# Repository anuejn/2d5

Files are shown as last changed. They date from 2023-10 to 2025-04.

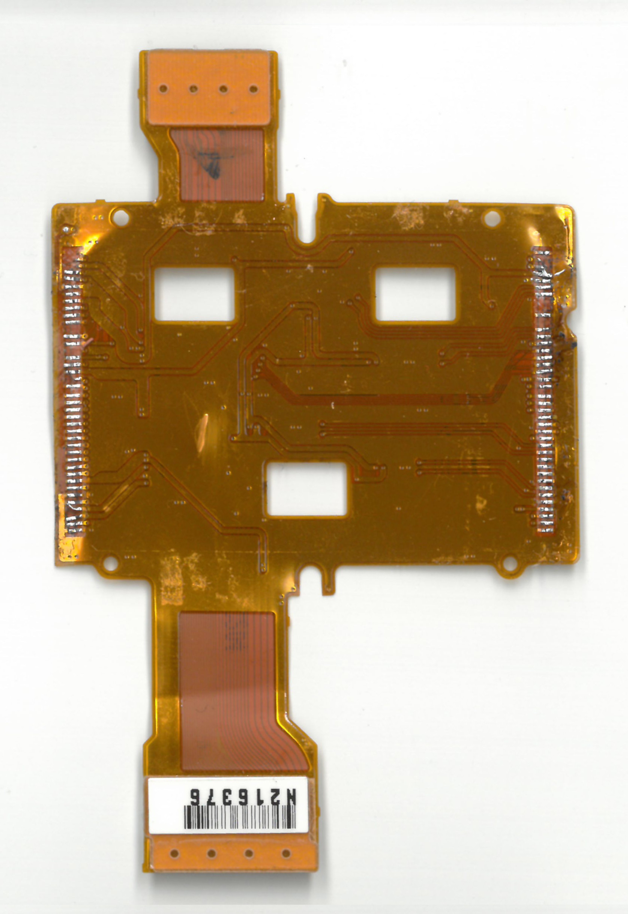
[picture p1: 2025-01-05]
carrier_tracing/front.jpg

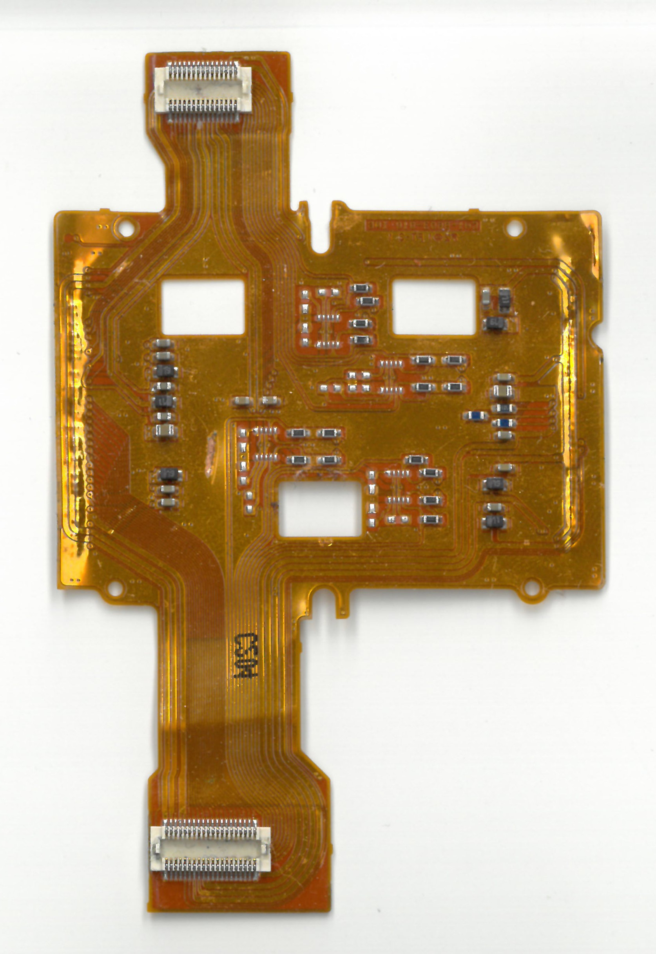
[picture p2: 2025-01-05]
carrier_tracing/back.jpg

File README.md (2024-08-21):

# Reverse engineering 5D mark II (5D2) image sensor

This repository contains notes tools for reverse engineering the image sensor of the Canon EOS 5D mark II
DSLR. The reverse engineering is work in progress and not in a state where the sensor is useable.
The image sensor is relatively cheap available (~40€) and has a "full frame" sized active area
(36mm × 24mm) with 5,616px × 3,744px (21.0 MP). The 5D mark II important in popularizing DSLR cameras
for video making and the Magic Lantern firmware was originally written for this camera.

The best place to start exploring the repository is reading the files on different topics in the
[`docs/`](docs/) directory. Other folders are less easy to follow but contain raw data obtained in 
the reverse engineering process.

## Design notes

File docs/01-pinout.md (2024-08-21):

# Pinout of the Sensor

For driving the sensor outside the camera, it is important to figure out its pinout. In the 5d2 the
sensor is mounted on a flex pcb. I will first focus on figuring out the connections of this flex-pcb.
After this, figuring out the pinout of the actual CMOS should be trivial if needed.

## Connectors

The sensor assembly has 3 connectors:

* larger stacking 20*2 position connector a closeup of the 40 pin connector
* smaller stacking 15*2 position connector a closeup of the 30 pin connector
* other 4 position connector probably going to the vibration cleaning of the sensor

The stacking connectors have the same pitch (0.466mm - 0.475mm measured probably 0.5mm) and are likely of the same series.
Mating height is ~1.5mm.

* Panasonic AXK5F should be fitting (probably original)
* TXGA FBB05001-F40S1003W5M / FBB05001-M40S1013W5M should fit (but is hard to obtain)
* Atom-connector BTB050040-F1S03201 / BTB050040-M1S03201 should fit
* XKB Connectivity X0511FVS-40B-LPV01 / X0511WVS-40A-LPV01 should fit and is on lcsc

A breakout board for intercepting communications between the camera and the sensor can be found
in the [connector_breakout](../connector_breakout) directory. It fits onto the mainboard and adapts the
connectors to 0.1" headers.
a picture of the breakout boards installed on the camera mainboard

## Pinout

Figuring out the pinout is a tricky process that I started with looking at the mainboard visually (see gimp files in `pictures/`),
using a continuity tester and doing different other measurements. After that, I measured voltages
at different pins and looked at the signals with an oscilloscope. Later, I also used different 
logic analyzer setups to trace the signals (see the `traces/` directory).
Throughout the process a warm round of guesswork guided me.
During the probing it was immensely helpful to have the breakout PCBs ordered with
white silkscreen to be able to write results directly to the breakout boards.

The results of my analysis can be found in the [connector pinouts table](../connector_pinouts.ods).
In the whole project, I refer to the pins using their coordinates in this spreadsheet.

The sensor outputs its analog data using differential pairs and requires
a bunch of different power supplies. To get a glimpse on how the interface could look like, see the
[datasheet of the Cypress IBIS4-14000](../interesting_datasheets/Cypress_Semiconductor-IBIS4-14000-M-datasheet.pdf).

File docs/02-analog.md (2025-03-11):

# Analog output of the CMOS

The image sensor outputs at four channels differentially. after each pixel, the differential output
goes to 0mV differential value. This is probably to enable Correlated Double Sampling (CDS).
Each side (positive and negative) is centered at ~1.4V and has 300-400mv Swing. The differential
values range from -600mV to +600mV.

## Possible ADCS

The stock adc/afe ic in the camera seems to sample at 24Msa/s.

| part | channels | sample rate [Msa/s] | bit depth | price | notes |
| :--- | :--- | :--- | :--- | :--- | :--- |
| VSP5610 | 4 | 8.75 | 16 | 6 | no register reference |
| ADDI7004  | 4 | 72 | 14 | 65$ | |
| ADC34J45  | 4 | 160 | 14 | 81$ | only ADC |
| ADC3422 | 4 | 50 | 12 | 25 | only ADC |
| ADC3244 | 2 | 125 | 14 | 26$ @1k | only ADC |
| HMCAD1520 | 4 | 160 | 12 | 121$ | only ADC |
| HMCAD1511 | 4 | 125 | 8 | 13$ | only ADC |
| AD9228 | 4 | 40 | 12 | 30 | only ADC |
| AD9235 | 1 | 65 | 12 | 11 | only ADC |
| ADS4222 | 2 | 65 | 12 | 11 | only ADC |
| AD9253 | 4 | 105 | 14 | 50 | only adc |
| AD9637 | 8 | 80 | 12 | 28 | only adc |
| MS9842SS  | 1 | 15 | 16 | 1 | same as HT82V42, only single ended input |
| LM98725 | 3 | 81 | 16 | 17 | |
| LM98714 | 3 | 45 | 16 | 12 | |

There is a test-board with a HMCAD1511 in the [zynq-test-board/](../zynq-test-board/) folder.

### HMCAD1511

I invested some efford trying to get 12 bit output from the HMCAD1511. This however is not trivial
and maybe outright impossible. It is not just the same die as the HMCAD1520 or at least it is 
configured a bit differently.

One possibility would be to use multiple 8 bit ADCs in an "Alexa Style" configuration with different
gains to reach higher dynamic range.

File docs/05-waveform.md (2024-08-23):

# Waveform of the image sensor

The image sensor consists of 3 main time periods. We decide that we base all our math off the middle
one, A line period. A line period starts at a rising edge of J21.

Signals to investigate:
* How does J10 actually look??? -> like in the newer la trace
* Is C3 having a signal? (line) -> yes
* Is C6 having a signal? (line) -> yes
* Is C5 having a signal? (frame) -> yes (once per frame for ~10 lines)

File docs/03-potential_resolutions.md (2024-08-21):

## Potential Resolutions:

The 5d2 sensor outputs analog values (no on chip ADC) with 4 channel readout.
The camera drives the sensor with a 24Mhz pixel clock. It is unclear how much faster the sensor can
be driven.

Required sample rates (purely theoretical; there will be some overhead):

| Format | resolution | framerate | pixel rate / 4 [Mpix/s] |
| :--- | :--- | :--- | :--- |
| FHD | 1920x1080  | 24 | 12.4416 |
| FHD actual cam  | 1872x1248  | 24 | 14.01753 |
| FHD | 1920x1080  | 30 | 15.552 |
| FHD actual cam  | 1872x1248  | 30 | 17.52192 | 
| HALF 16:9 | 2808x1580  | 24 | 26.61984 |
| FHD | 1920x1080  | 60 | 31.104 |
| HALF | 2808x1872  | 24 | 31.53945 |
| HALF 16:9 | 2808x1580  | 30 | 33.2748 |
| HALF | 2808x1872  | 30 | 39.42432 |
| camera 1080p | 5568x1044  | 30 | 43.59744 |
| FULL 3-lineskip | 5568x1248  | 30 | 52.11648 |
| 4k 16:9 (CROP)  | 4096x2304  | 24 | 56.62310 |
| HALF 16:9 | 2808x1580  | 60 | 66.5496 |
| 4k 16:9 (CROP)  | 4096x2304  | 30 | 70.77888 |
| HALF | 2808x1872  | 60 | 78.84864 |
| FULL 21:9 | 5616x2407  | 24 | 81.10627 |
| FULL 21:9 | 5616x2407  | 30 | 101.3828 |
| FULL 16:9 | 5616x3159  | 24 | 106.4456 |
| FULL | 5616x3744  | 24 | 126.1578 |
| FULL 16:9 | 5616x3159  | 30 | 133.0570 |
| 4k 16:9 (CROP)  | 4096x2304  | 60 | 141.5577 |
| FULL | 5616x3744  | 30 | 157.6972 |

Notes:

* The camera is [reported to use a column 3x binning and row 3x skipping](https://www.magiclantern.fm/forum/index.php?topic=16516.0)
  in its video mode. The FHD mode seems to use on-chip row and column skipping and a slightly-less than FHD readout with digital upscaling
  for the FHD video output.
* It is unclear what other row / column subsampling modes are possible with the sensor interface (concerns HALF, FHD and CROP modes)
* 4k DCI would have a crop factor of 1.371 (vs 1.6 for APSC)
* USB 3.0 can theoretically transport 500Mbyte/s as a theoretical maximum and probably not much more than 400Mbyte/s in practice.
* Actual ADC speed would need to be twice as high for correlated double sampling (CDS) or would require additional analog circutry

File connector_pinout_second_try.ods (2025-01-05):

line |  |  | 2v8
 |  | GND | 5v
frame | 5v | GND | pxclk
line | pxclk | GND | GND
2v9 | GND | startup | GND
line | Analog Data | startup | line
-1v3 | GND | 2v | frame
1v3 | Analog Data | 1v3 | line
5v | GND | 5v | line
-1v3 | Analog Data | 5v | line
 | GND | GND | x
SPI DATA | Analog Data | Analog Data
SPI CLK | GND | GND | line
SPI CS | GND | Analog Data | line
line | 1v3 | GND | line
 |  | Analog Data | line
 |  | GND | startup
 |  | Analog Data | 3v
 |  | GND | line
 |  | 1v5
 | 5v
 | 3v
 | 2v9
 | 2v8
 | 2v
 | 1v5
 | 1v3
 | -1v3

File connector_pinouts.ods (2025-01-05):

 |  | Pinout 30pin connector |  |  |  |  |  | Pinout 40pin connector
 |  |  |  |  |  |  |  |  |  |  | pulses per Y-reset
41,958Khz | line? | Digital North | Digital North | 0 |  |  | Startup / Shutdown / mode change | Digital North | PWR north (without c) | 2,8v
 | floating? | Digital North | Digital North | 0 |  |  |  | GND | 5V | 5,081v
 | floating? | Digital North | 5V | 5,08v |  |  |  | GND | Digital North | Pxclk | 2753 | !!!
 | line | Digital North | Digital North | Pxclk |  |  |  | GND | GND
 | 2.4v | Digital North | GND |  |  | Startup hang? |  | Digital South | GND
41,958Khz | line | Digital North | Analog Data |  |  | Startup / Shutdown |  | Digital South | Digital North | line? | 2681
 | -1,316v | PWR | GND |  |  | Enable? | 2,029v | PWR South | Digital North | Y-reset? | 1
0.86uF to GND | 1,3762v / 0.9v | PWR thin | Analog Data |  |  | Startup charge? | 1,3048v | PWR South | Digital North | line many pulses | 3576
 | 4,969v | PWR | GND |  |  |  | 5,082v | 5V | Digital North | active high line | 894 | Maybe 0
 | -1,3163v | PWR pair | Analog Data |  |  |  | 5,082v | 5V | Digital North | line enable? | 894 | Maybe 0
 | ???GND??? | ??? | GND |  |  |  |  | GND | Digital North | startup? | 0
30Hz / 2Mhz / 4Mhz | Data? | UNK via | Analog Data |  |  |  |  | Analog Data | Digital North | ????????
30Hz / 2Mhz / 4Mhz | ClK? | 2 | GND |  |  |  |  | GND | Digital North | line multiple pulses? |  | ??
30Hz | 6 Pulses per frame? | UNK via | GND |  |  |  |  | Analog Data | Digital North | line with skip? | 1788
41,958Khz | line | UNK via | PWR? | 1,305v | Startup charge? |  |  | GND | Digital North | line? | 893
 |  |  |  |  |  |  |  | Analog Data | Digital North | line? | 893
 |  |  |  |  |  |  |  | GND | Digital North | startup? | -
 |  |  |  |  |  |  |  | Analog Data | Digital North | enable? | -
 |  |  |  |  |  |  |  | GND | Digital North | line? | 894
 |  |  |  |  |  | Enable? | 1,501v | PWR south | Digital North | 0 | -
 |  | Voltages:
 |  |  | 5V
 |  |  | 2.8
 |  |  | 2.4
 |  |  | 2.
 |  |  | 1.5
 |  |  | 1.3
 |  |  | -1.3

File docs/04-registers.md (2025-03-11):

# Registers of the Sensor
* The Sensor seems to have 6 registers (0 - 5) with 12 bit each
* they are written with an SPI bus that is active when CS (C16) is high
* There are other devices on the SPI bus (probably the ADTGs), so not all trafic is for the sensor
* The clock is C15, data is on C14. Data is valid on the rising edge of the clock.
* The SPI bus has transactions with 16 bits each. The first 4 bits are the adress of the register
  while the last 12 bits are the value. 

There is documentation on the register map [in the magic lantern wiki](https://magiclantern.fandom.com/wiki/ADTG)
and in the magic lantern [adtg_gui code](https://github.com/reticulatedpines/magiclantern_simplified/blob/df4c7bd32ec0cd65a4b6aacdd7ec5cce1c560135/modules/dev_tools/adtg_gui/adtg_gui.c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).

## Register states in different situations: 
This section contains observations of the register set in different situations. 
They are the state during capture and are captured with either a glasgow or a logic analyzer.

### Different modes
```
photo:           0203 1C00 2008 3007 4242 5C05
normal liveview: 020f 1c00 240e 3005 4242 5c01
fhd:             020f 1c00 240e 3005 4242 5c01
```

### Experimentation with the LiveView Zoom
```
5x zoom center:              020f 1e6a 210e 3005 4242 5c01
5x zoom upper right corner:  020f 1d20 220e 3005 4242 5c01
5x zoom upper left corner:   020f 1d20 200e 3005 4242 5c01
5x zoom lower right corner:  020f 1c18 220e 3005 4242 5c01
5x zoom lower left corner:   020f 1c18 200e 3005 4242 5c01
```

10x modes have the exact same registers and are implemented in software.

### Experimentation with ISO (all of this is in LiveView)
```
ISO 100:  0203 1c00 240e 3005 4242 5c01
ISO 160:  0207 1c00 240e 3005 4242 5c01
ISO 320:  020b 1c00 240e 3005 4242 5c01
ISO 640:  020f 1c00 240e 3005 4242 5c01
ISO 1250: 0213 1c00 240e 3005 4244 5c01
ISO 2500: 0213 1c00 240e 3005 4244 5001
```

## Conclusions:

conclusions prefixed with "ML:" are not my findings but rather copied from the Magic Lantern

### CMOS[0]
```
---- ---- --xx ML: default 11, setting to 00 results in dark image with very low stdev
---- ---x xx-- ISO coarse (0 - 4)
---- xxx- ---- ML: ISO2
---x ---- ---- ML: ISO2 enable (according to ML)
--x- ---- ---- ML: enables vertical OB clamping maybe (setting it to 0 results in severe horizontal banding that looks like random walk)
-x-- ---- ---- ML: compresses the image horizontally (left side squashed, right side black)
0010 0000 0011 "normal"
```

### CMOS[1]
```
---- ---x xxx-  y start offset 0 - 12
1100 0000 0000 "normal"
1110 0110 1010 "zoom center"
1101 0010 0000 "zoom upper"
1100 0001 1000 "zoom lower"

top to bottom sweep zoomed in:
1101 0110 0010
1101 1010 0100
1101 1110 0110
1110 0010 1000
1110 0110 1010
1110 1010 1100
1110 1110 1110
1111 0011 0000
1111 0111 0010
1111 1011 0100
1111 1111 0110
1100 0001 1000
```

### CMOS[2]
```
-x-- ---- ---- binning?
--xx ---- ---- coarse x offset? (left = 0, center = 1, right = 2)
---- ---- -xx- only set in liveview-esque modes
0000 0000 1000 "photo"
0100 0000 1110 "liveview"
0001 0000 1110 "zoom center"
0010 0000 1110 "zoom right"
0000 0000 1110 "zoom left"
0010 0000 1100 Temporary cleanup state during zoomed in sweep in LV
```

### CMOS[3]
```
---- ---- --x-  magic photo bit?
0000 0000 0111 "photo"
0000 0000 0101 "liveview
```

### CMOS[4]
```
---- ---- -xx- analog mux (one hot) for high conversion gain? (0b01 = ISO < 1250; 0b10 = ISO >= 1250)
---x ---- ---- ML: looks like some vertical dual ISO
-x-- ---- ---- ML: seems to cleanup 0.2 or 0.25 stops of shadow noise
No effect observed on the other bits.
0010 0100 0010 ISO < 1250
0010 0100 0100 ISO >= 1250
```

### CMOS[5]
```
xx-- ---- ---- ISO related (00 = LOW ISO, 11 = ISO >= 2500)
---- ---- -x-- Photo Mode Bit
1100 0000 0101 Photo
1100 0000 0001 LV
0000 0000 0001 LV ISO >= 2500
0100 0000 0101 Temporary cleanup state during zoomed in sweep in LV
```

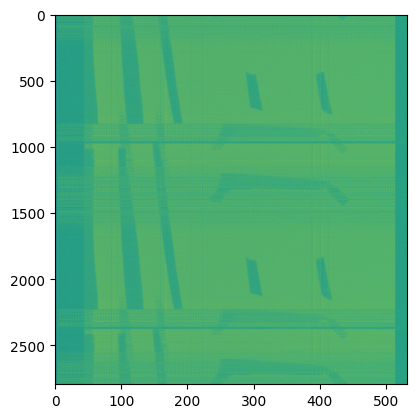
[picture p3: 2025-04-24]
traces/25-04-24/output.png

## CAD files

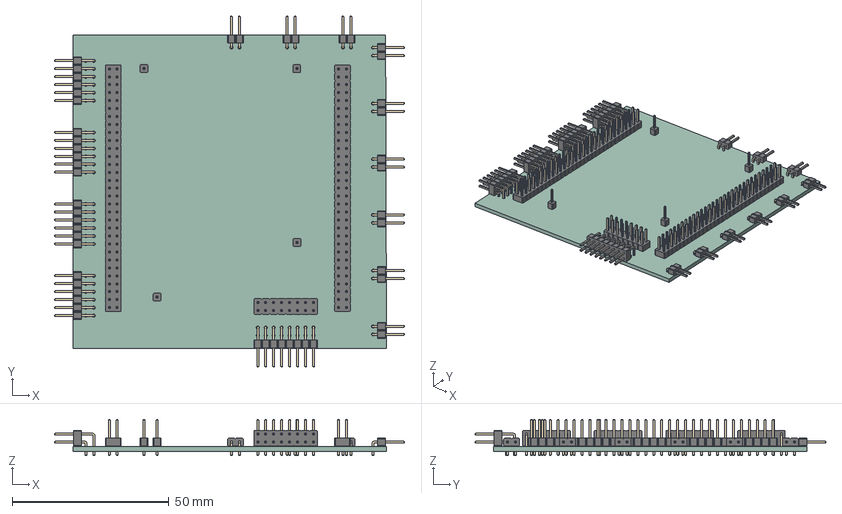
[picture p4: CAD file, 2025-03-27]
boards/hedgehog/5d2_pmod/5d2_pmod.step
111.7 x 112.0 x 11.5 mm
PinHeader_2x31_P254mm_Vertical x 2
PinHeader_1x01_P254mm_Vertical x 4
PinHeader_2x06_P254mm_Horizontal x 4
PinHeader_1x02_P254mm_Horizontal x 9
PinHeader_2x08_P254mm_Vertical
PinHeader_2x08_P254mm_Horizontal
5d2_pmod_PCB

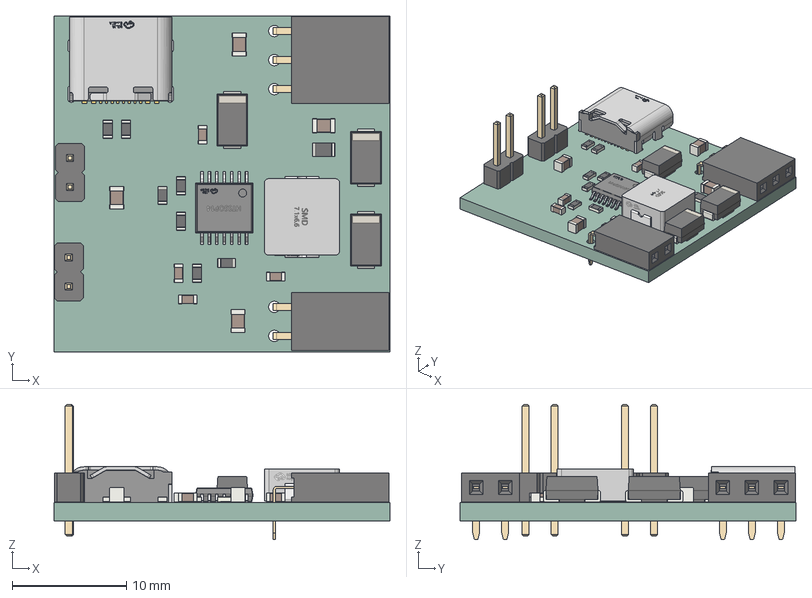
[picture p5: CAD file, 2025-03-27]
boards/hedgehog/power_base/power_base.step
29.4 x 29.4 x 11.8 mm
PinHeader_1x02_P254mm_Vertical x 2
PinSocket_1x03_P254mm_Horizontal
USB-C-SMD_TYPE-C-6PIN-2MD-073
C_0603_1608Metric x 4
C_0805_2012Metric x 4
HTSSOP-14_L5.0-W4.4-H1.2-LS6.4-P0.65
IND-SMD_L7.1-W6.6-H2.8
R_0603_1608Metric x 7
D_SMA x 3
PinSocket_1x02_P254mm_Horizontal
R_0805_2012Metric
power_base_PCB

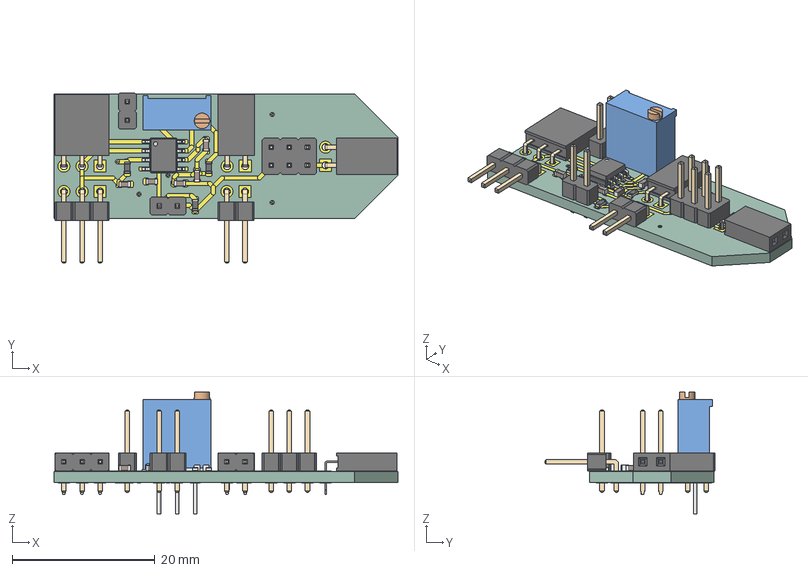
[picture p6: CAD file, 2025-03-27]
boards/hedgehog/power_leg_positive/power_leg_positive.step
48.3 x 23.9 x 17.1 mm
SOIC_8_39x49mm_P127mm
C_0603_1608Metric x 5
R_0603_1608Metric x 3
PinHeader_1x03_P254mm_Horizontal
PinHeader_1x02_P254mm_Vertical x 2
PinSocket_1x02_P254mm_Horizontal x 2
PinSocket_1x03_P254mm_Horizontal
PinHeader_1x02_P254mm_Horizontal
PinHeader_2x03_P254mm_Vertical
Potentiometer_Bourns_3296W_Vertical
power_leg_positive_track_1
power_leg_positive_track_2
power_leg_positive_track_3
power_leg_positive_track_4
power_leg_positive_track_5
power_leg_positive_track_6
power_leg_positive_track_7
power_leg_positive_track_8
power_leg_positive_track_9
power_leg_positive_track_10
power_leg_positive_track_11
power_leg_positive_track_12
power_leg_positive_track_13
power_leg_positive_track_14
power_leg_positive_track_15
power_leg_positive_track_16
power_leg_positive_track_17
power_leg_positive_track_18
power_leg_positive_track_19
power_leg_positive_track_20
power_leg_positive_track_21
power_leg_positive_track_22
power_leg_positive_track_23
power_leg_positive_track_24
power_leg_positive_track_25
power_leg_positive_track_26
power_leg_positive_track_27
power_leg_positive_track_28
power_leg_positive_track_29
power_leg_positive_track_30
power_leg_positive_track_31
power_leg_positive_track_32
power_leg_positive_track_33
power_leg_positive_track_34
power_leg_positive_track_35
power_leg_positive_track_36
power_leg_positive_track_37
power_leg_positive_track_38
power_leg_positive_track_39
power_leg_positive_track_40
power_leg_positive_track_41
power_leg_positive_track_42
power_leg_positive_track_43
power_leg_positive_track_44
power_leg_positive_track_45
power_leg_positive_track_46
power_leg_positive_track_47
power_leg_positive_track_48
power_leg_positive_track_49
power_leg_positive_track_50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

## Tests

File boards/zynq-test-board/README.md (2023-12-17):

# zynq test board

This board is a "cape" for the [z-turn lite](https://www.myirtech.com/list.asp?id=565)zynq SBC and
should serve as a development basis for interfacing the sensor. 
It features an HMCAD1511TR as ADC and appropriate power-supplies. Otherwise it does very little.

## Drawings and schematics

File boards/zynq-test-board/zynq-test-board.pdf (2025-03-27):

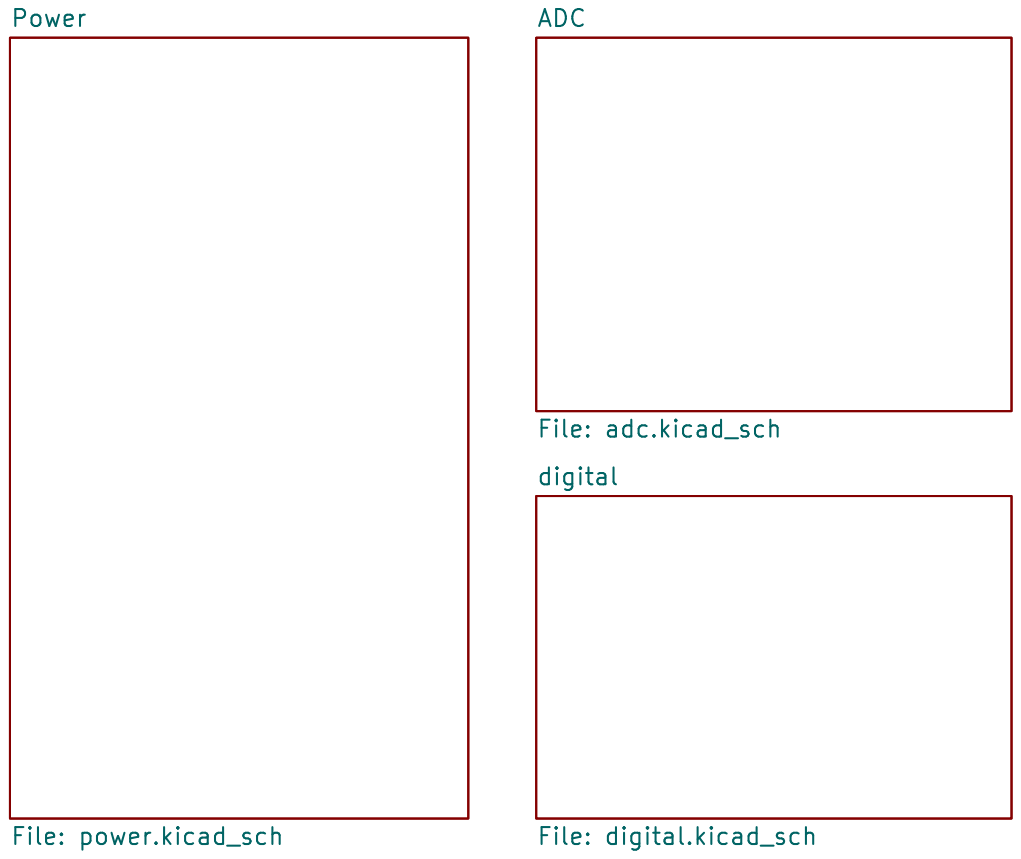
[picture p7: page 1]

digital File: digital.kicad_sch ADC

File: zynq-test-board.kicad_sch Sheet: / Apertus

Id: 1/16 Title: 2D5 experiment board

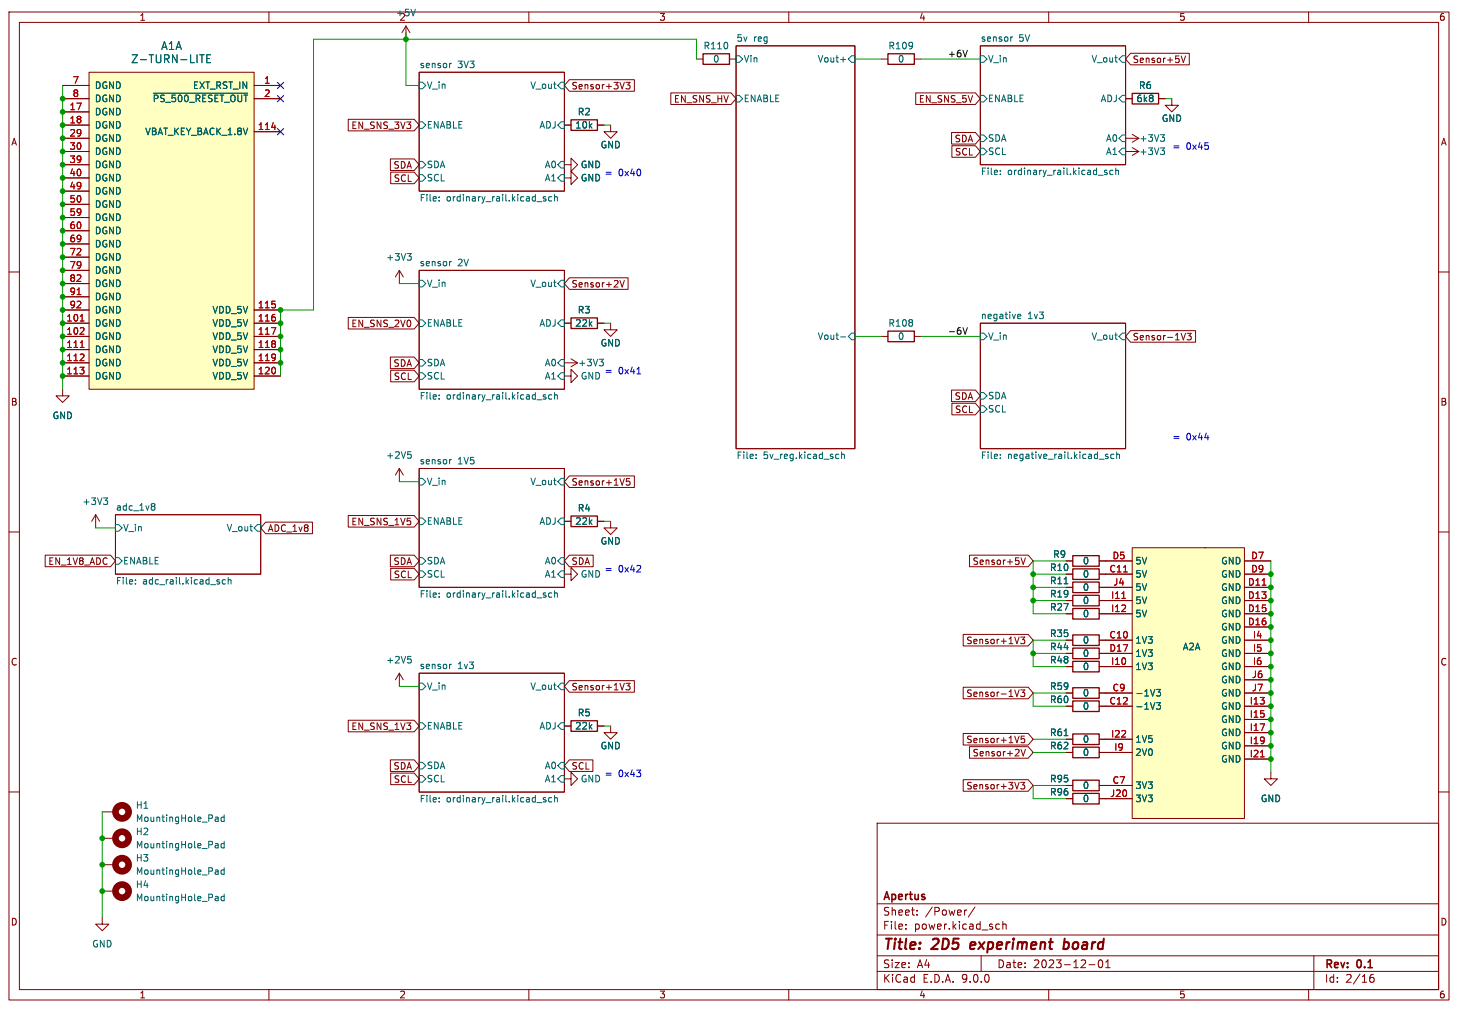
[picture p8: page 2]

File: power.kicad_sch Sheet: /Power/ Apertus

Id: 2/16 Title: 2D5 experiment board

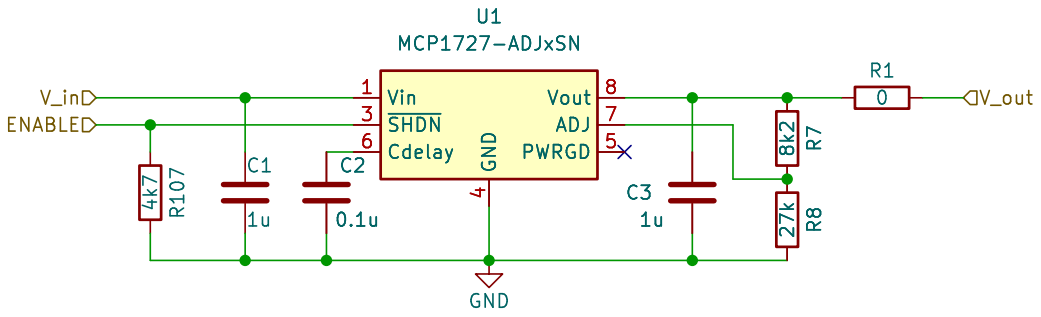
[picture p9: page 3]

File: adc_rail.kicad_sch Sheet: /Power/adc_1v8/
Id: 3/16 Title: 2D5 experiment board

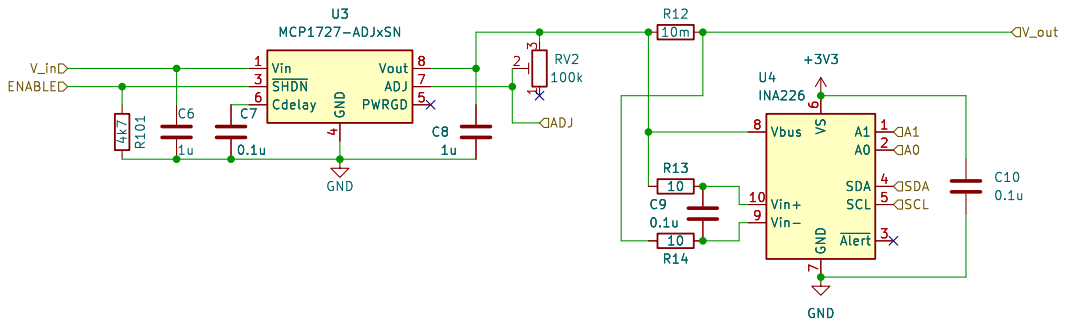
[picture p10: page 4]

7 A1 1 A0 2 SDA 4 SCL 5 ~{Alert}3 GND

Id: 3/16 Title: 2D5 experiment board

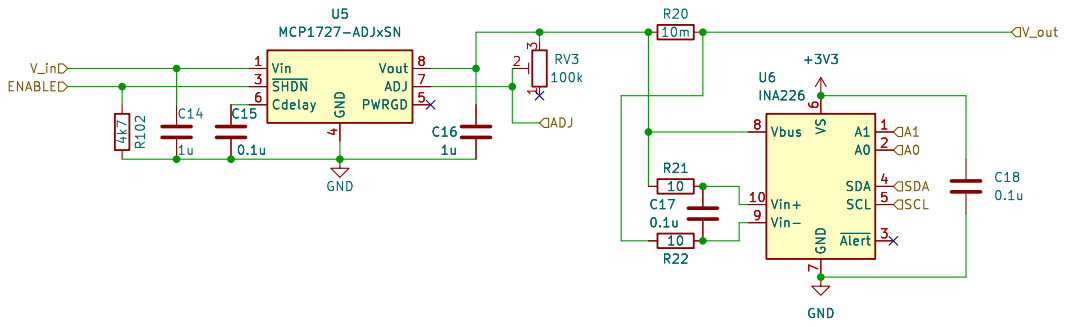
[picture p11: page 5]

7 A1 1 A0 2 SDA 4 SCL 5 ~{Alert}3 GND

Id: 4/16 Title: 2D5 experiment board

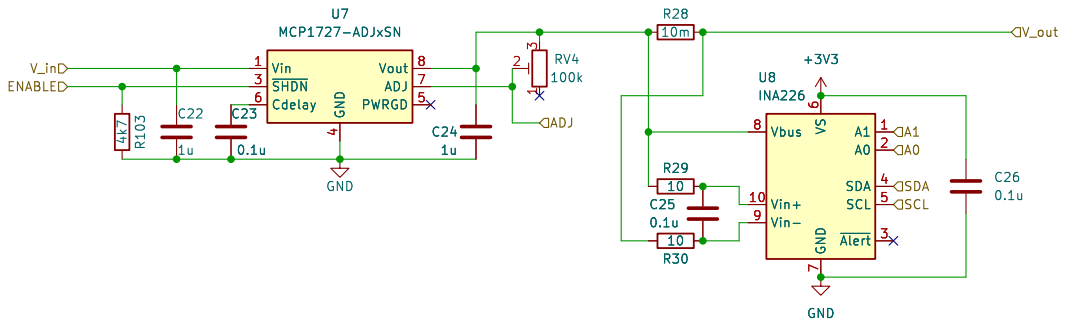
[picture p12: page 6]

7 A1 1 A0 2 SDA 4 SCL 5 ~{Alert}3 GND

Id: 5/16 Title: 2D5 experiment board

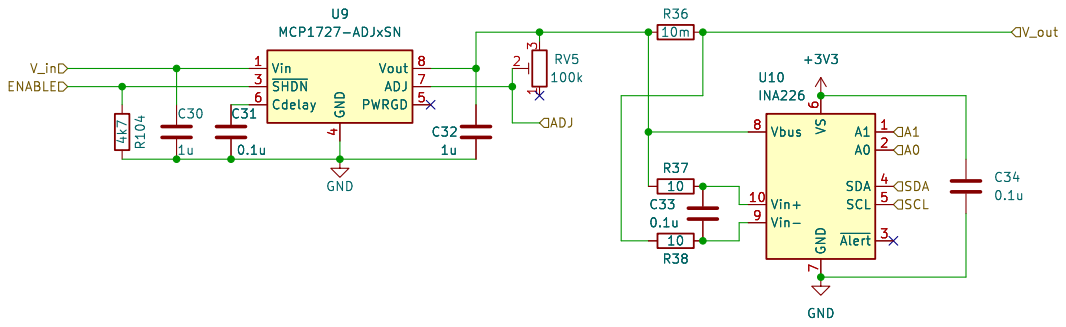
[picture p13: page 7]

7 A1 1 A0 2 SDA 4 SCL 5 ~{Alert}3 GND

Id: 6/16 Title: 2D5 experiment board

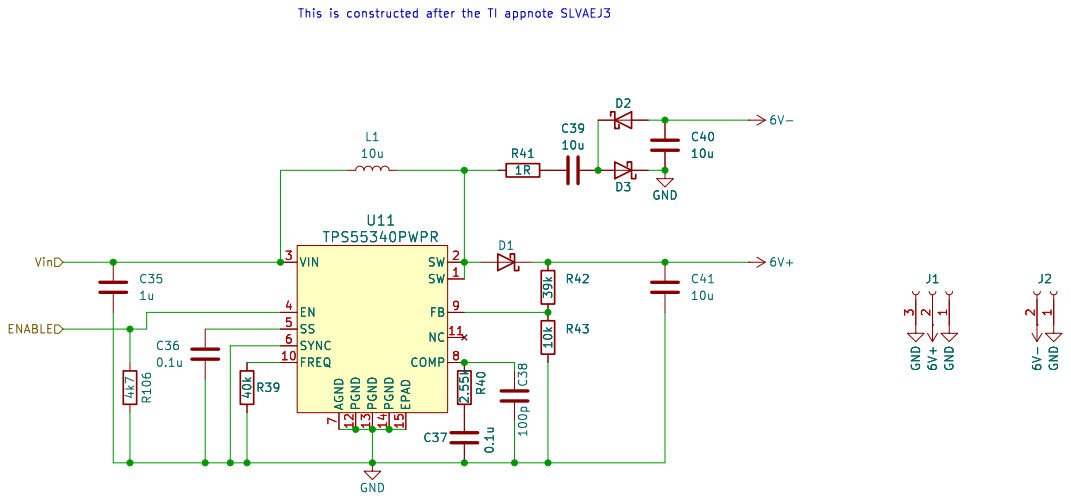
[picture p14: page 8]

7 PGND 12 PGND 13 PGND 14 EPAD 15 SW 2 SW 1 FB 9 NC 11 COMP 8 C37 0.1u R40 2.55k R41

7 PGND 12 PGND 13 PGND 14 EPAD 15 SW 2 SW 1 FB 9 NC 11 COMP 8 U11 TPS55340PWPR GND

Id: 7/16 Title: 2D5 experiment board

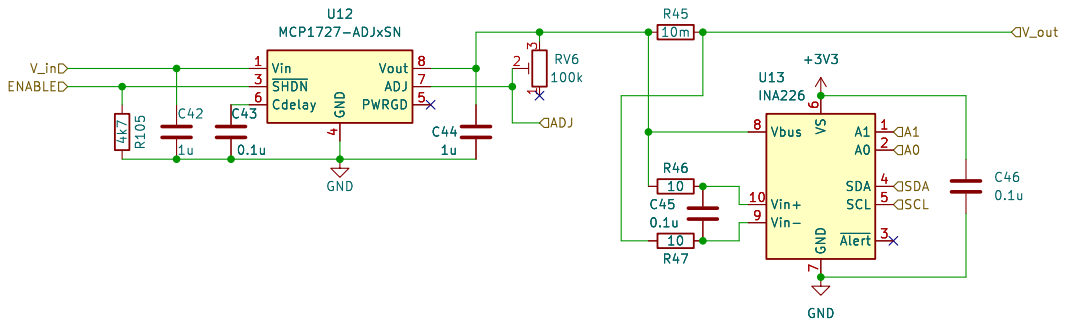
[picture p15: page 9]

7 A1 1 A0 2 SDA 4 SCL 5 ~{Alert}3 GND

Id: 8/16 Title: 2D5 experiment board

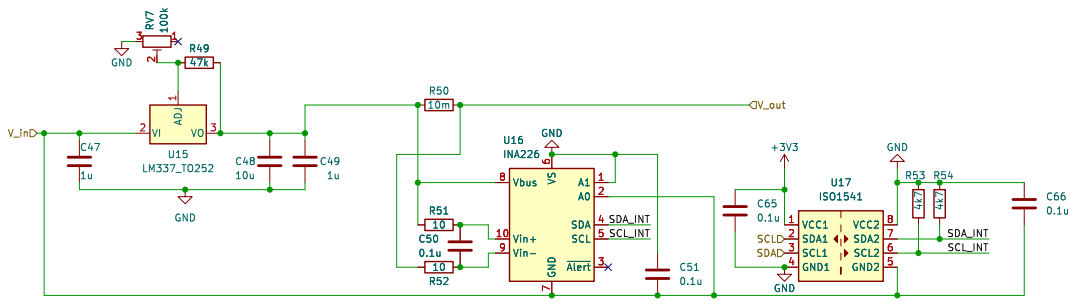
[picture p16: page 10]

7 A1 1 A0 2 SDA 4 SCL 5 ~{Alert}3 GND

Id: 9/16 Title: 2D5 experiment board

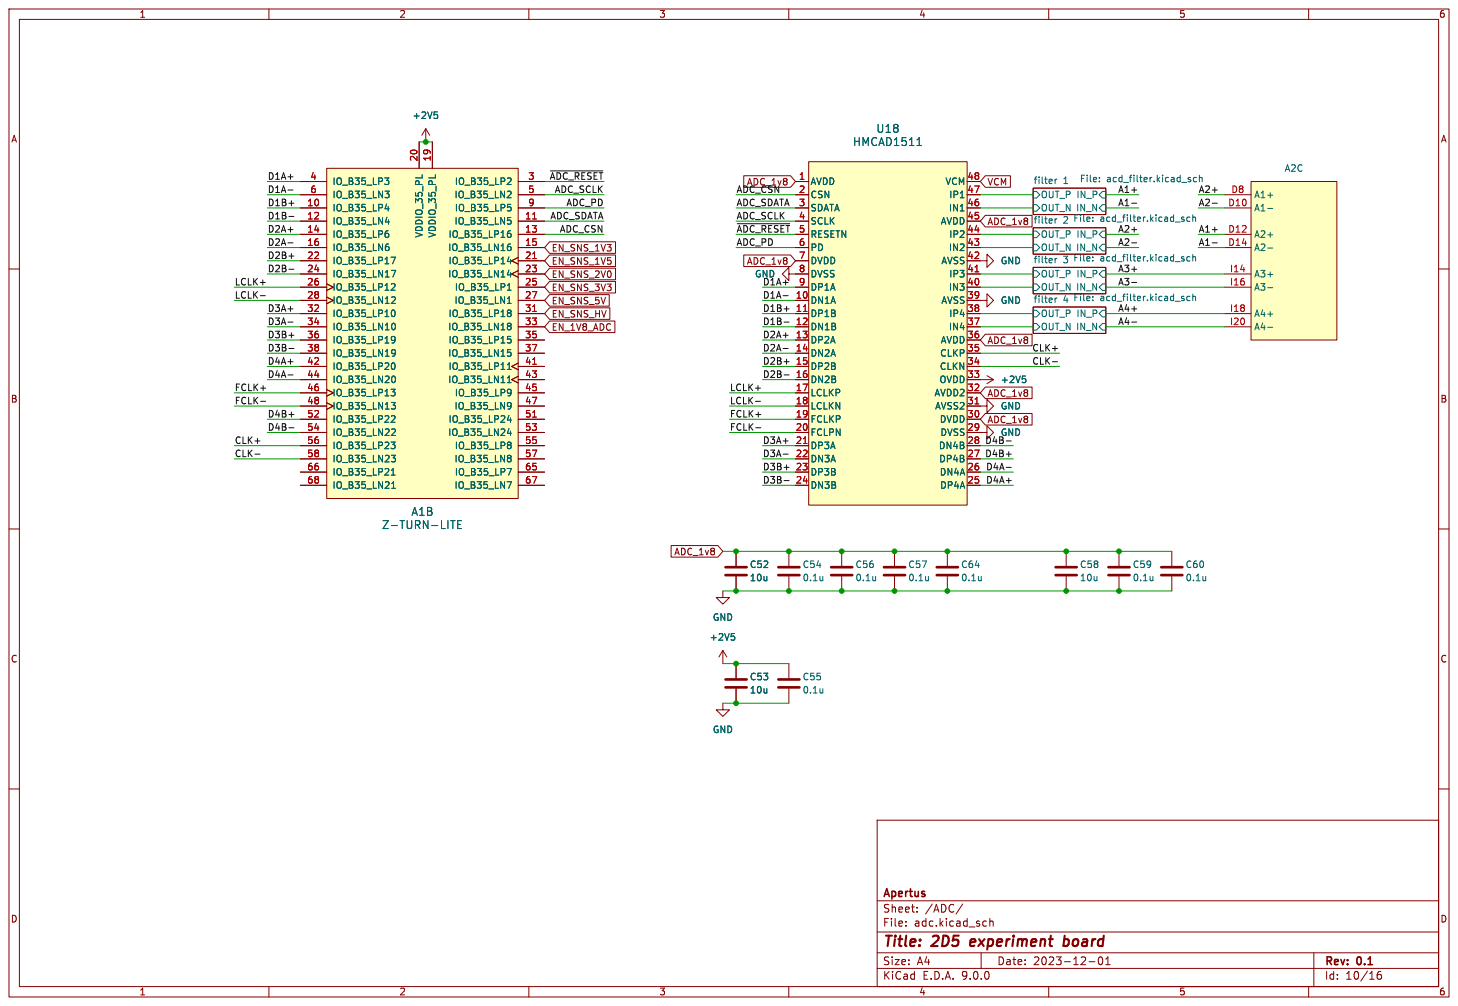
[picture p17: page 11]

File: adc.kicad_sch Sheet: /ADC/ Apertus

Id: 10/16 Title: 2D5 experiment board

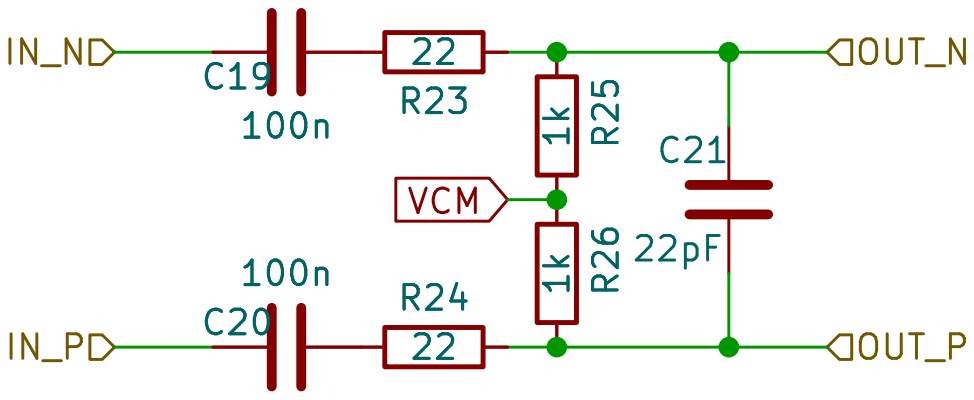
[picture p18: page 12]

Id: 11/16 Title: 2D5 experiment board


Id: 12/16 Title: 2D5 experiment board


Id: 13/16 Title: 2D5 experiment board


Id: 14/16 Title: 2D5 experiment board


Apertus
File: digital.kicad_sch Sheet: /digital/
Id: 15/16 Title: 2D5 experiment board

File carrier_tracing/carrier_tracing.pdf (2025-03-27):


81012141618202224262830 +1V3_TOP GND GND GND GND +5Vb +5Vb GND GND GND GND GND +5V +2V8 +1V3_BOT +1V5 GND

+1V3_TOP
D7 GND GND GND GND

smells more analog domain

and some kind of core voltage?

these might be related to analog IO?
though on the wrong side

Id: 1/5 Title: File: carrier_tracing.kicad_sch Sheet: /

only used in the unpopulated


Id: 2/5 Title: File: mystery_ic.kicad_sch Sheet: /mystery_0/ R22R


Id: 3/5 Title: File: mystery_ic.kicad_sch Sheet: /mystery_1/ R17R


Id: 4/5 Title: File: mystery_ic.kicad_sch Sheet: /mystery_2/ R5R


Id: 5/5 Title: File: mystery_ic.kicad_sch Sheet: /mystery_3/ R11R

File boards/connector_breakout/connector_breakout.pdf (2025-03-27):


Id: 1/1 Title: File: connector_breakout.kicad_sch Sheet: /

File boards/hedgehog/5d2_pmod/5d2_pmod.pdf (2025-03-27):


Id: 1/1 Title: File: 5d2_pmod.kicad_sch Sheet: / 13579

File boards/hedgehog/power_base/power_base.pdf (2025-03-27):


10u GND GND GND GND

7 PGND 12 PGND 13 PGND 14 EPAD 15 SW 2 SW 1 FB 9 NC 11 COMP 8 C9

7 PGND 12 PGND 13 PGND 14 EPAD 15 SW 2 SW 1 FB 9 NC 11 COMP 8 U1 TPS55340PWPR

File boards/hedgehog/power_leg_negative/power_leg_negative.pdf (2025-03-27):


Id: 1/1 Title: File: power_leg_negative.kicad_sch Sheet: /

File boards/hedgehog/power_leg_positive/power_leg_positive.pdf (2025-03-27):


Id: 1/1 Title: File: power_leg_positive.kicad_sch Sheet: /

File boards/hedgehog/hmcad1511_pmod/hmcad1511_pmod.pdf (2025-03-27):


Id: 1/1 Title: HMCAD1511 PMOD Module

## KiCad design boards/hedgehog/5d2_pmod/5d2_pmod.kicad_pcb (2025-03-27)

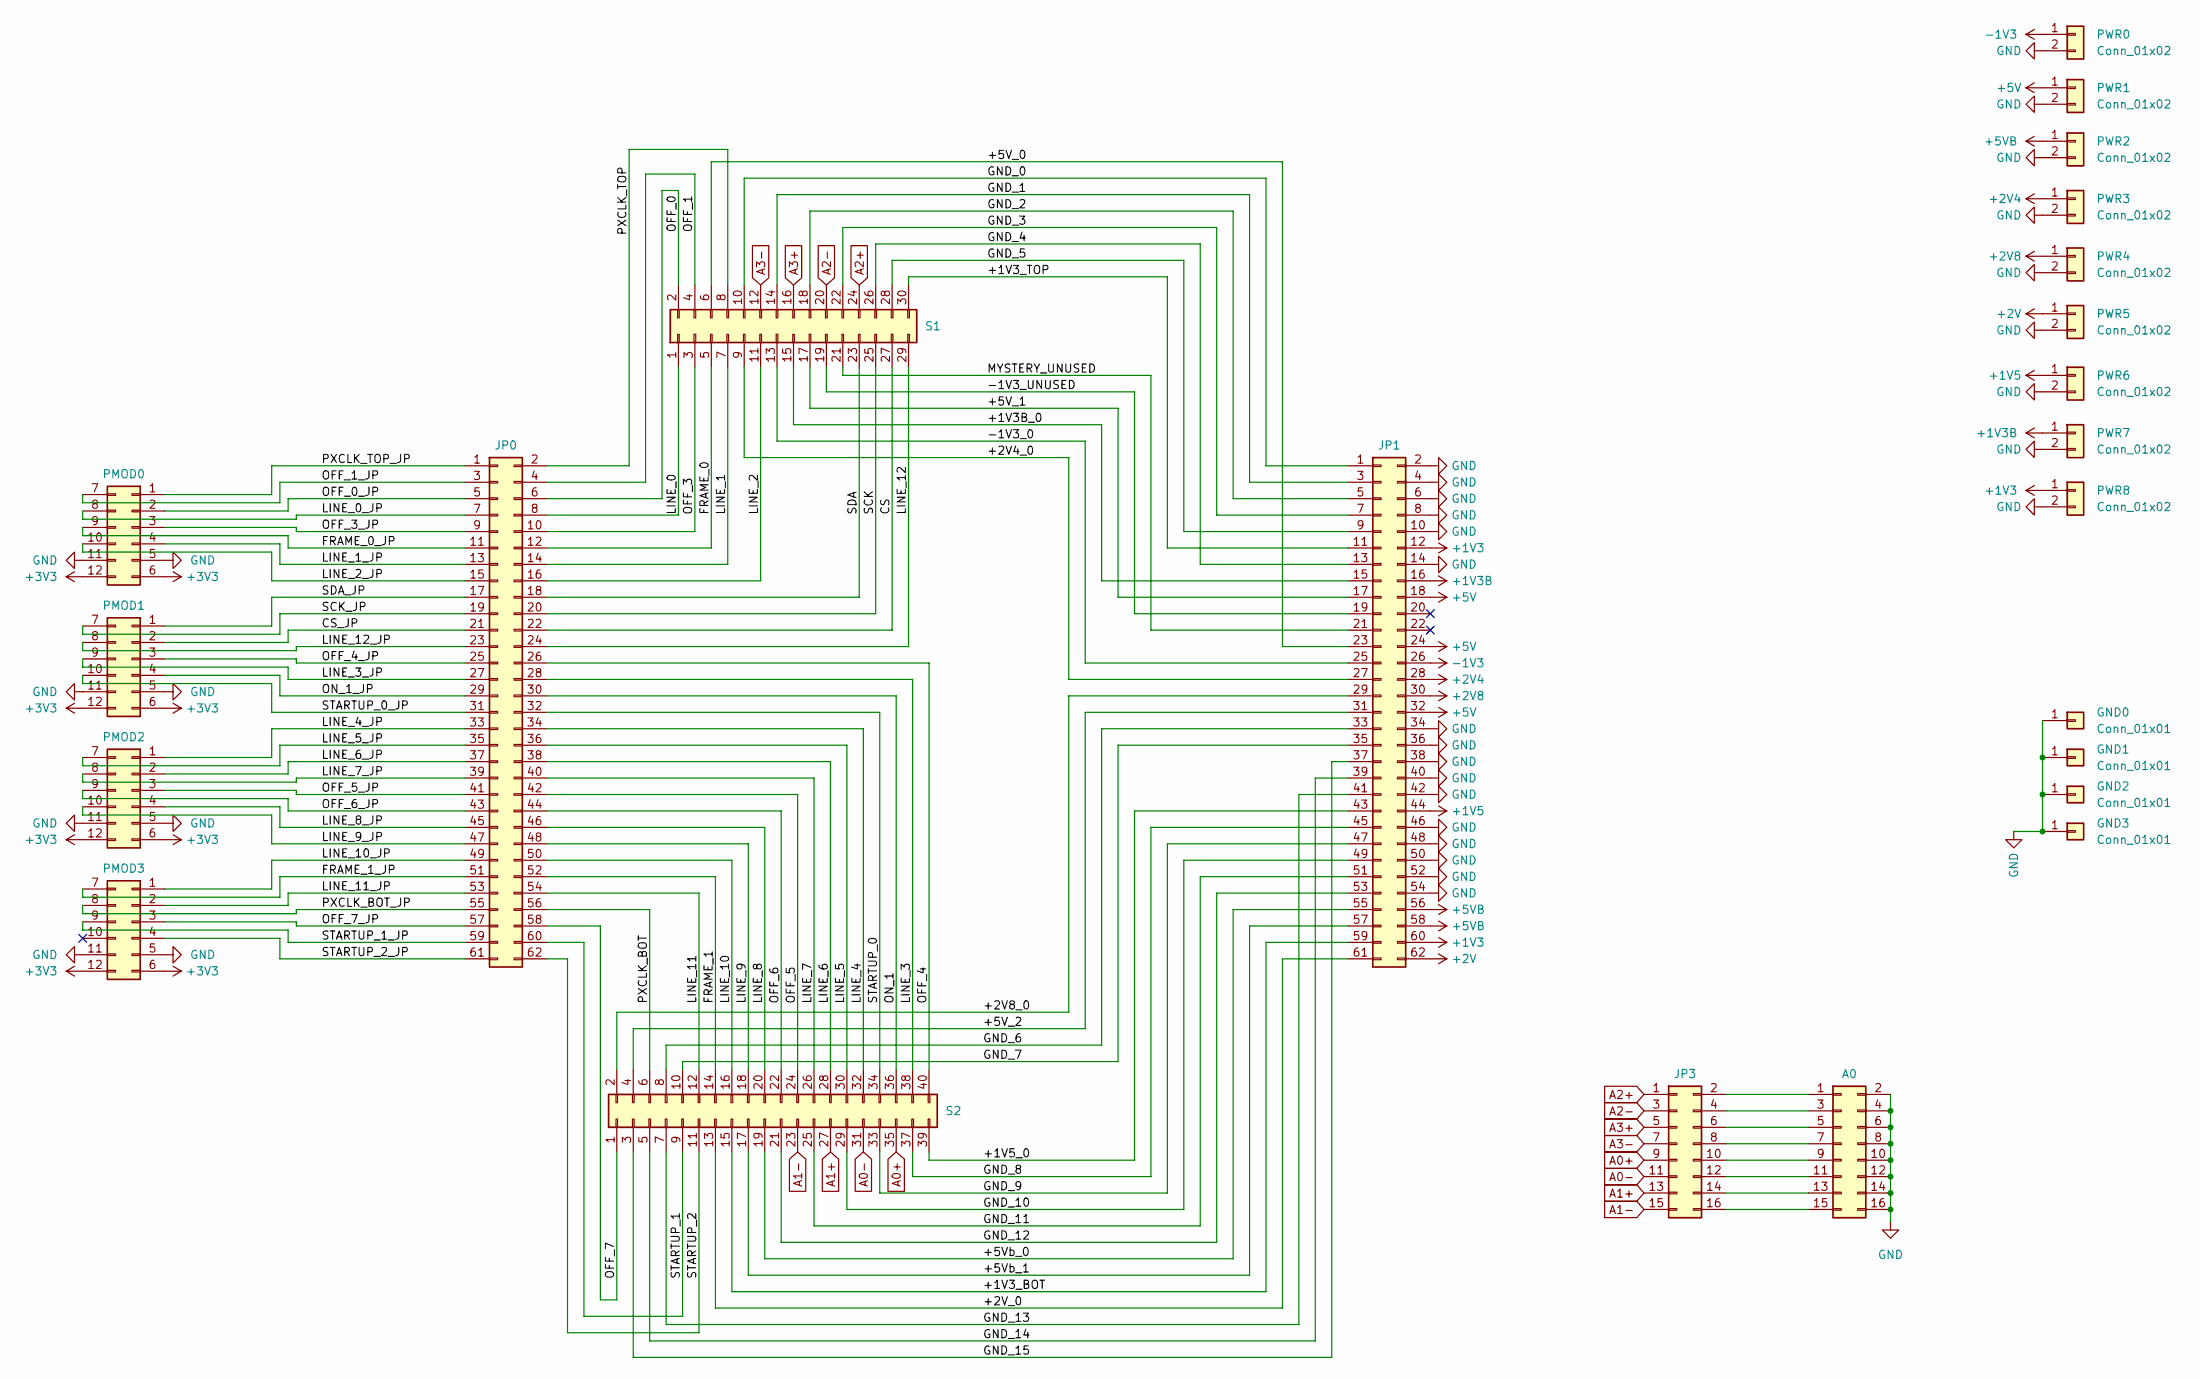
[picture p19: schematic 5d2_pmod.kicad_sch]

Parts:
A0: Conn_02x08_Odd_Even; PinHeader_2x08_P2.54mm_Horizontal
GND0, GND1, GND2, GND3: Conn_01x01; PinHeader_1x01_P2.54mm_Vertical
JP0, JP1: Conn_02x31_Odd_Even; PinHeader_2x31_P2.54mm_Vertical
JP3: Conn_02x08_Odd_Even; PinHeader_2x08_P2.54mm_Vertical
PMOD0, PMOD1, PMOD2, PMOD3: Conn_02x06_Top_Bottom; PMOD
PWR0, PWR1, PWR2, PWR3, PWR4, PWR5, PWR6, PWR7, PWR8: Conn_01x02; PinHeader_1x02_P2.54mm_Horizontal
S1: Conn_02x15_Odd_Even; AXK5F30
S2: Conn_02x20_Odd_Even; AXK5F40

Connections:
+1V3: JP1.12, JP1.60, PWR8.1
+1V3B: JP1.16, PWR7.1
+1V5: JP1.44, PWR6.1
+2V: JP1.62, PWR5.1
+2V4: JP1.28, PWR3.1
+2V8: JP1.30, PWR4.1
+3V3: PMOD0.6, PMOD0.12, PMOD1.6, PMOD1.12, PMOD2.6, PMOD2.12, PMOD3.6, PMOD3.12
+5V: JP1.18, JP1.24, JP1.32, PWR1.1
+5VB: JP1.56, JP1.58, PWR2.1
-1V3: JP1.26, PWR0.1
/+1V3B_0: JP1.15, S1.15
/+1V3_BOT: JP1.59, S2.15
/+1V3_TOP: JP1.11, S1.30
/+1V5_0: JP1.43, S2.39
/+2V4_0: JP1.27, S1.9
/+2V8_0: JP1.29, S2.2
/+2V_0: JP1.61, S2.13
/+5V_0: JP1.23, S1.6
/+5V_1: JP1.17, S1.17
/+5V_2: JP1.31, S2.4
/+5Vb_0: JP1.55, S2.19
/+5Vb_1: JP1.57, S2.17
/-1V3_0: JP1.25, S1.13
/-1V3_UNUSED: JP1.19, S1.19
/CS: JP0.22, S1.27
/CS_JP: JP0.21, PMOD1.2
/FRAME_0: JP0.12, S1.5
/FRAME_0_JP: JP0.11, PMOD0.9
/FRAME_1: JP0.52, S2.14
/FRAME_1_JP: JP0.51, PMOD3.7
/GND_0: JP1.1, S1.10
/GND_1: JP1.3, S1.14
/GND_2: JP1.5, S1.18
/GND_3: JP1.7, S1.22
/GND_4: JP1.13, S1.26
/GND_5: JP1.9, S1.28
/GND_6: JP1.33, S2.8
/GND_7: JP1.35, S2.10
/GND_8: JP1.45, S2.37
/GND_9: JP1.47, S2.33
/GND_10: JP1.49, S2.29
/GND_11: JP1.51, S2.25
/GND_12: JP1.53, S2.21
/GND_13: JP1.41, S2.7
/GND_14: JP1.39, S2.5
/GND_15: JP1.37, S2.3
/LINE_0: JP0.8, S1.1
/LINE_0_JP: JP0.7, PMOD0.8
/LINE_1: JP0.14, S1.7
/LINE_1_JP: JP0.13, PMOD0.4
/LINE_2: JP0.16, S1.11
/LINE_2_JP: JP0.15, PMOD0.10
/LINE_3: JP0.28, S2.38
/LINE_3_JP: JP0.27, PMOD1.9
/LINE_4: JP0.34, S2.32
/LINE_4_JP: JP0.33, PMOD2.1
/LINE_5: JP0.36, S2.30
/LINE_5_JP: JP0.35, PMOD2.7
/LINE_6: JP0.38, S2.28
/LINE_6_JP: JP0.37, PMOD2.2
/LINE_7: JP0.40, S2.26
/LINE_7_JP: JP0.39, PMOD2.8
/LINE_8: JP0.46, S2.20
/LINE_8_JP: JP0.45, PMOD2.4
/LINE_9: JP0.48, S2.18
/LINE_9_JP: JP0.47, PMOD2.10
/LINE_10: JP0.50, S2.16
/LINE_10_JP: JP0.49, PMOD3.1
/LINE_11: JP0.54, S2.12
/LINE_11_JP: JP0.53, PMOD3.2
/LINE_12: JP0.24, S1.29
/LINE_12_JP: JP0.23, PMOD1.8
/MYSTERY_UNUSED: JP1.21, S1.21
/OFF_0: JP0.6, S1.2
/OFF_0_JP: JP0.5, PMOD0.2
/OFF_1: JP0.4, S1.4
/OFF_1_JP: JP0.3, PMOD0.7
/OFF_3: JP0.10, S1.3
/OFF_3_JP: JP0.9, PMOD0.3
/OFF_4: JP0.26, S2.40
/OFF_4_JP: JP0.25, PMOD1.3
/OFF_5: JP0.42, S2.24
/OFF_5_JP: JP0.41, PMOD2.3
/OFF_6: JP0.44, S2.22
/OFF_6_JP: JP0.43, PMOD2.9
/OFF_7: JP0.58, S2.1
/OFF_7_JP: JP0.57, PMOD3.3
/ON_1: JP0.30, S2.36
/ON_1_JP: JP0.29, PMOD1.4
/PXCLK_BOT: JP0.56, S2.6
/PXCLK_BOT_JP: JP0.55, PMOD3.8
/PXCLK_TOP: JP0.2, S1.8
/PXCLK_TOP_JP: JP0.1, PMOD0.1
/SCK: JP0.20, S1.25
/SCK_JP: JP0.19, PMOD1.7
/SDA: JP0.18, S1.23
/SDA_JP: JP0.17, PMOD1.1
/STARTUP_0: JP0.32, S2.34
/STARTUP_0_JP: JP0.31, PMOD1.10
/STARTUP_1: JP0.60, S2.9
/STARTUP_1_JP: JP0.59, PMOD3.9
/STARTUP_2: JP0.62, S2.11
/STARTUP_2_JP: JP0.61, PMOD3.4
A0+: JP3.9, S2.35
A0-: JP3.11, S2.31
A1+: JP3.13, S2.27
A1-: JP3.15, S2.23
A2+: JP3.1, S1.24
A2-: JP3.3, S1.20
A3+: JP3.5, S1.16
A3-: JP3.7, S1.12
GND: A0.2, A0.4, A0.6, A0.8, A0.10, A0.12, A0.14, A0.16, GND0.1, GND1.1, GND2.1, GND3.1, JP1.2, JP1.4, JP1.6, JP1.8, JP1.10, JP1.14, JP1.34, JP1.36, JP1.38, JP1.40, JP1.42, JP1.46, JP1.48, JP1.50, JP1.52, JP1.54, PMOD0.5, PMOD0.11, PMOD1.5, PMOD1.11, PMOD2.5, PMOD2.11, PMOD3.5, PMOD3.11, PWR0.2, PWR1.2, PWR2.2, PWR3.2, PWR4.2, PWR5.2, PWR6.2, PWR7.2, PWR8.2
unnamed: A0.1, JP3.2
unnamed: A0.3, JP3.4
unnamed: A0.5, JP3.6
unnamed: A0.7, JP3.8
unnamed: A0.9, JP3.10
unnamed: A0.11, JP3.12
unnamed: A0.13, JP3.14
unnamed: A0.15, JP3.16

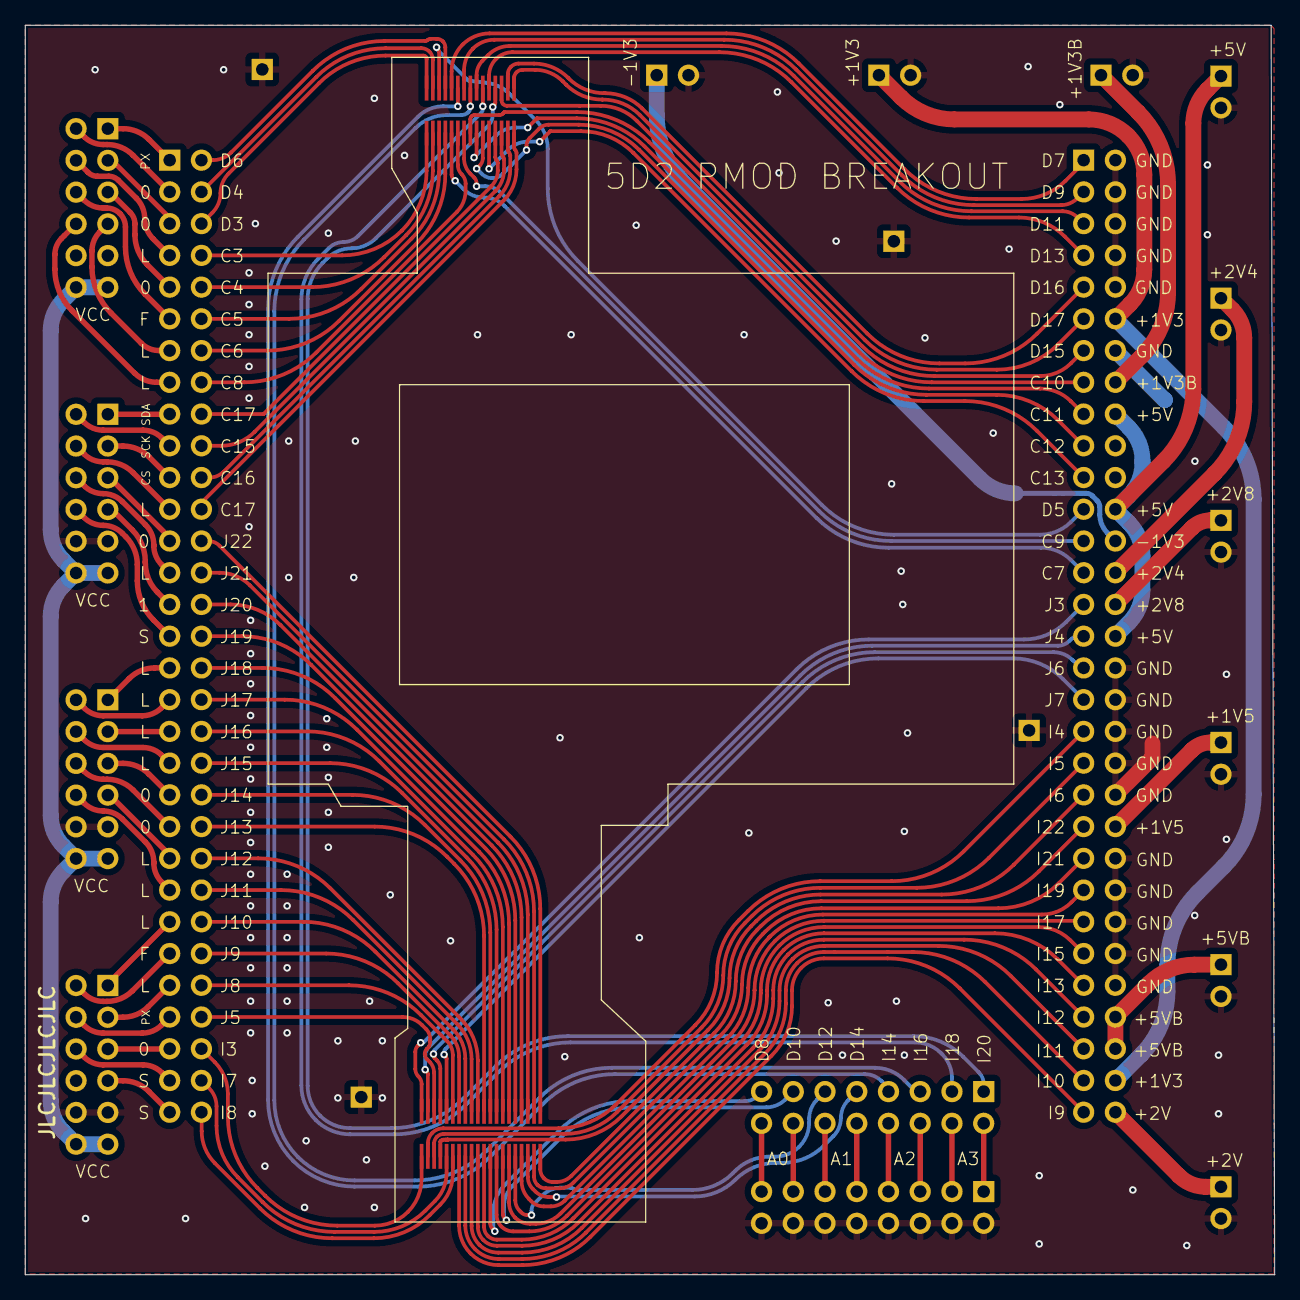
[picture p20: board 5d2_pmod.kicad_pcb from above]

Board: 2 copper layers, 100.0 x 100.0 mm, 23 parts (0 on the bottom side), 120 nets.

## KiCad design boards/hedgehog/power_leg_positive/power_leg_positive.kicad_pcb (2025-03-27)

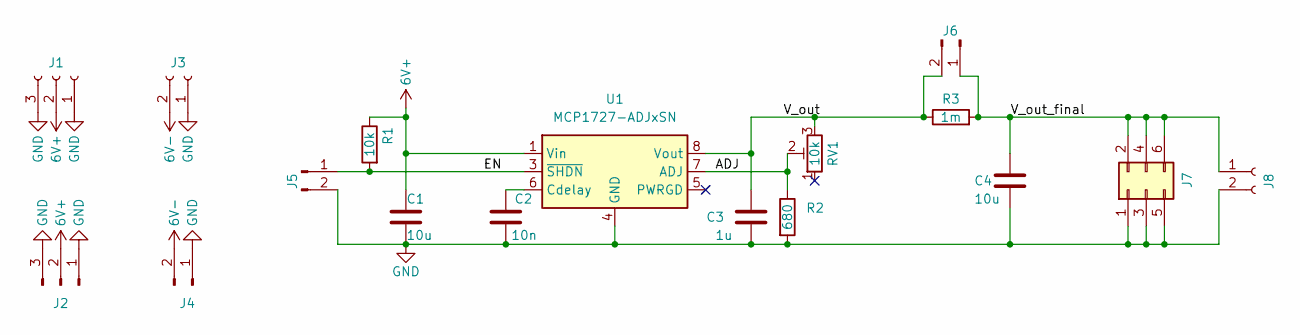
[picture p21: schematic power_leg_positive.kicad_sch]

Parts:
C1, C4: 10u; C_0603_1608Metric
C2: 10n; C_0603_1608Metric
C3: 1u; C_0603_1608Metric
J1: Conn_01x03_Socket; PinSocket_1x03_P2.54mm_Horizontal
J2: Conn_01x03_Pin; PinHeader_1x03_P2.54mm_Horizontal
J3, J8: Conn_01x02_Socket; PinSocket_1x02_P2.54mm_Horizontal
J4: Conn_01x02_Pin; PinHeader_1x02_P2.54mm_Horizontal
J5, J6: Conn_01x02_Pin; PinHeader_1x02_P2.54mm_Vertical
J7: Conn_02x03_Odd_Even; PinHeader_2x03_P2.54mm_Vertical
R1: 10k; R_0603_1608Metric
R2: 680; R_0603_1608Metric
R3: 1m; R_1206_3216Metric
RV1: 10k; Potentiometer_Bourns_3296W_Vertical; MPN C118963
U1: MCP1727-ADJxSN; SOIC-8_3.9x4.9mm_P1.27mm

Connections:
6V+: C1.1, J1.2, J2.2, R1.1, U1.1 (Vin), U1.2 (Vin)
6V-: J3.2, J4.2
/ADJ: R2.1, RV1.2, U1.7 (ADJ)
/EN: J5.1, R1.2, U1.3 (~SHDN)
/V_out: C3.1, J6.2, R3.1, RV1.3, U1.8 (Vout)
/V_out_final: C4.1, J6.1, J7.2, J7.4, J7.6, J8.1, R3.2
GND: C1.2, C2.1, C3.2, C4.2, J1.1, J1.3, J2.1, J2.3, J3.1, J4.1, J5.2, J7.1, J7.3, J7.5, J8.2, R2.2, U1.4 (GND)
unnamed: C2.2, U1.6 (Cdelay)

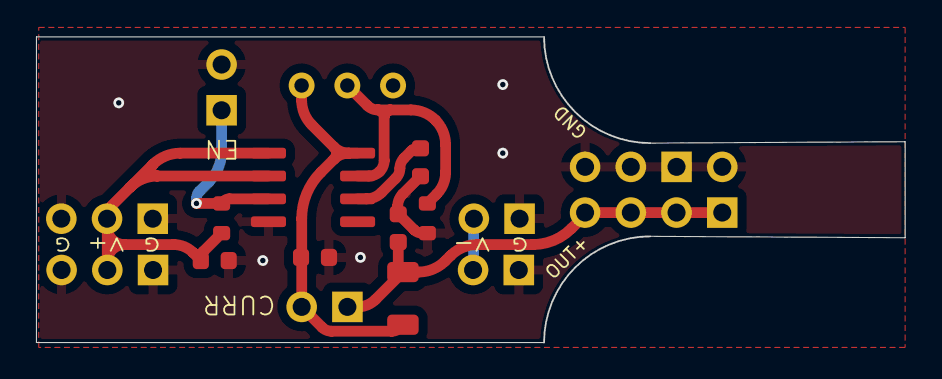
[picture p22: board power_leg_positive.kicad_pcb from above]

Board: 2 copper layers, 48.3 x 17.0 mm, 17 parts (0 on the bottom side), 8 nets.

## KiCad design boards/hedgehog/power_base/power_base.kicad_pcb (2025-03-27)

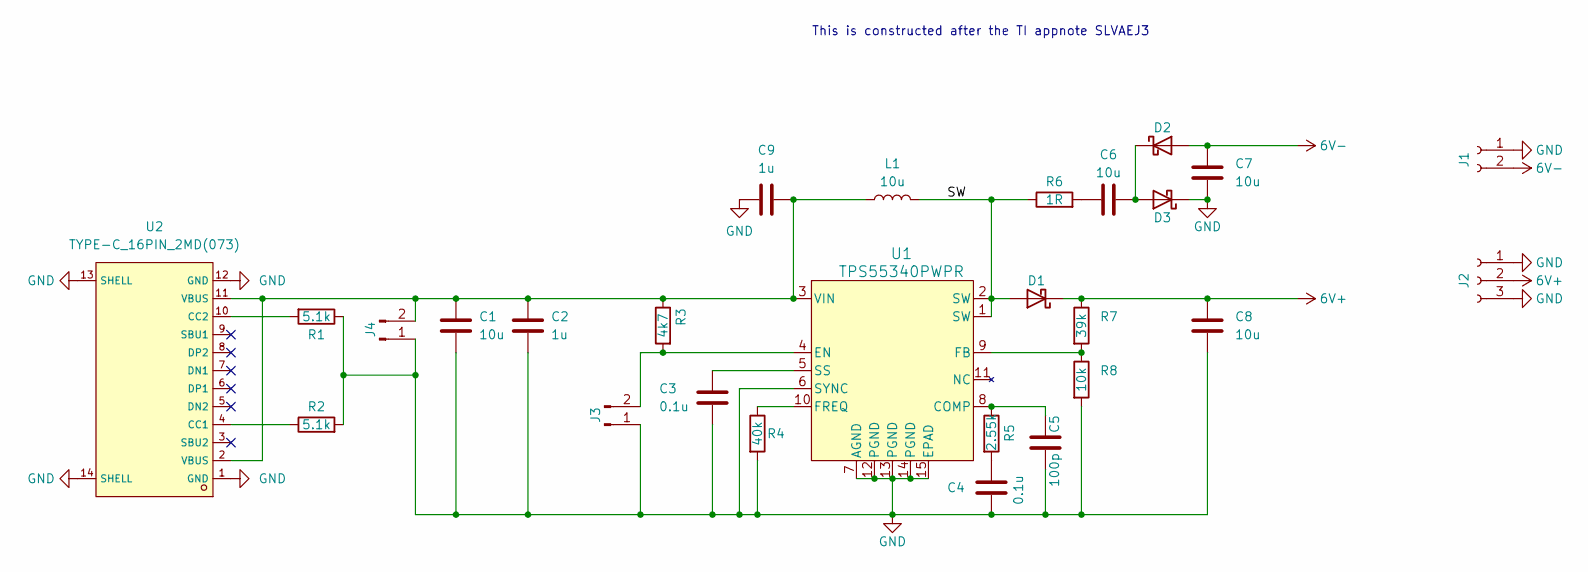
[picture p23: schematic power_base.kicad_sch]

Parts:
C1, C6, C7, C8: 10u; C_0603_1608Metric; LCSC C15850
C2, C9: 1u; C_0603_1608Metric; LCSC C15849
C3, C4: 0.1u; C_0603_1608Metric; LCSC C14663
C5: 100p; C_0603_1608Metric; LCSC C14858
D1, D2, D3: D_Schottky; D_SMA; MPN C8678; LCSC C8678
J1: Conn_01x02_Socket; PinSocket_1x02_P2.54mm_Horizontal
J2: Conn_01x03_Socket; PinSocket_1x03_P2.54mm_Horizontal
J3, J4: Conn_01x02_Pin; PinHeader_1x02_P2.54mm_Vertical
L1: 10u; IND-SMD_L7.3-W6.6; MPN C128692; LCSC C128692
R1, R2: 5.1k; R_0603_1608Metric; LCSC C23186
R3: 4k7; R_0603_1608Metric; LCSC C23162
R4: 40k; R_0603_1608Metric; LCSC C23153
R5: 2.55k; R_0603_1608Metric; LCSC C25965
R6: 1R; R_0805_2012Metric; LCSC C25271
R7: 39k; R_0603_1608Metric; LCSC C23153
R8: 10k; R_0603_1608Metric; LCSC C25804
U1: TPS55340PWPR; PWP14; LCSC C43862
U2: TYPE-C_16PIN_2MD(073); USB-C-SMD_TYPE-C-6PIN-2MD-073; LCSC C2765186

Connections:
6V+: C8.1, D1.1 (K), J2.2, R7.1
6V-: C7.1, D2.2 (A), J1.2
/SW: D1.2 (A), L1.2, R6.1, U1.1 (SW), U1.2 (SW)
GND: C1.2, C2.2, C3.2, C4.2, C5.2, C7.2, C8.2, C9.2, D3.1 (K), J1.1, J2.1, J2.3, J3.1, J4.1, R1.1, R2.2, R4.2, R8.2, U1.6 (SYNC), U1.7 (AGND), U1.12 (PGND), U1.13 (PGND), U1.14 (PGND), U1.15 (EPAD), U2.1 (GND), U2.12 (GND), U2.13 (SHELL), U2.14 (SHELL)
unnamed: C4.1, R5.2
unnamed: C6.1, R6.2
unnamed: C6.2, D2.1 (K), D3.2 (A)
unnamed: J3.2, R3.2, U1.4 (EN)
unnamed: C1.1, C2.1, C9.1, J4.2, L1.1, R3.1, U1.3 (VIN), U2.2 (VBUS), U2.11 (VBUS)
unnamed: C5.1, R5.1, U1.8 (COMP)
unnamed: R7.2, R8.1, U1.9 (FB)
unnamed: R4.1, U1.10 (FREQ)
unnamed: C3.1, U1.5 (SS)
unnamed: R2.1, U2.4 (CC1)
unnamed: R1.2, U2.10 (CC2)

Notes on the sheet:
This is constructed after the TI appnote SLVAEJ3

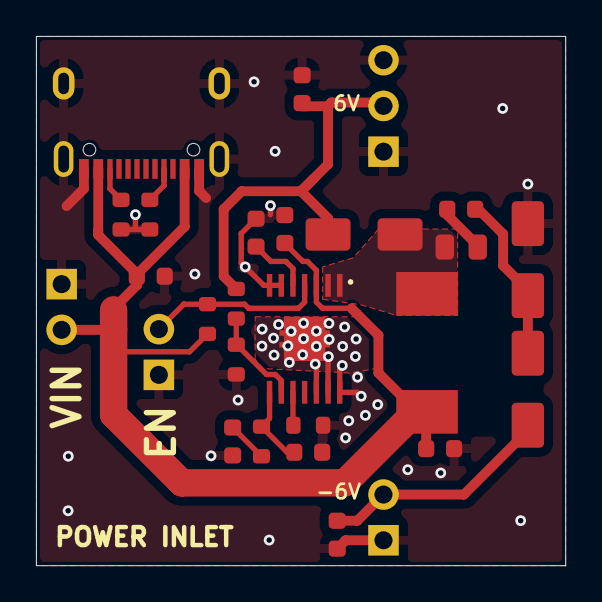
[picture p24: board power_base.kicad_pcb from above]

Board: 2 copper layers, 29.4 x 29.4 mm, 27 parts (0 on the bottom side), 15 nets.

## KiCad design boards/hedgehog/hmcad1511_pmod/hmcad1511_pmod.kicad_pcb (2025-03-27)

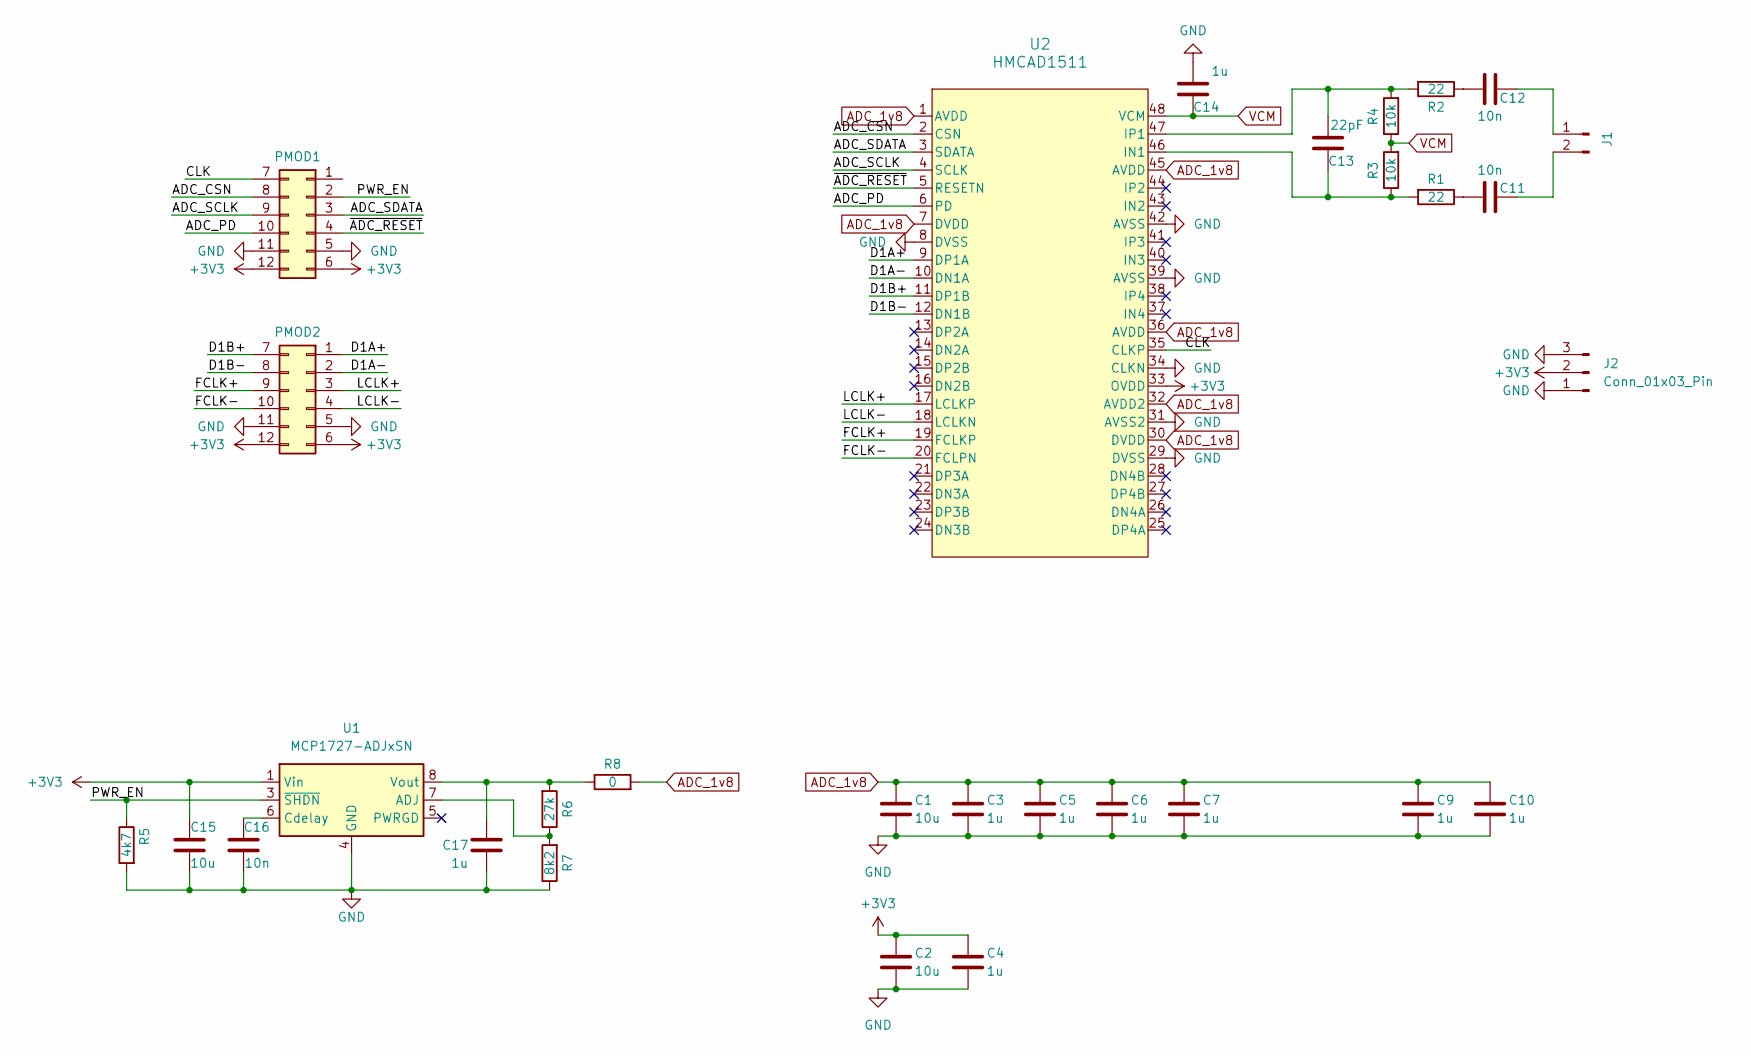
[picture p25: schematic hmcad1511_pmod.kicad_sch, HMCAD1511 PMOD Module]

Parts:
C1, C2, C15: 10u; C_0603_1608Metric
C3, C4, C5, C6, C7, C9, C10, C14, C17: 1u; C_0603_1608Metric
C11, C12, C16: 10n; C_0603_1608Metric
C13: 22pF; C_0603_1608Metric
J1: Conn_01x02_Pin; PinHeader_1x02_P2.54mm_Horizontal
J2: Conn_01x03_Pin; PinHeader_1x03_P2.54mm_Horizontal
PMOD1, PMOD2: Conn_02x06_Top_Bottom; PMOD
R1, R2: 22; R_0603_1608Metric
R3, R4: 10k; R_0603_1608Metric
R5: 4k7; R_0603_1608Metric
R6: 27k; C_0603_1608Metric
R7: 8k2; C_0603_1608Metric
R8: 0; C_0603_1608Metric
U1: MCP1727-ADJxSN; SOIC-8_3.9x4.9mm_P1.27mm
U2: HMCAD1511; QFN_48_ADI

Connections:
+3V3: C2.1, C4.1, C15.1, J2.2, PMOD1.6, PMOD1.12, PMOD2.6, PMOD2.12, U1.1 (Vin), U1.2 (Vin), U2.33 (OVDD)
/ADC_CSN: PMOD1.8, U2.2 (CSN)
/ADC_PD: PMOD1.10, U2.6 (PD)
/ADC_SCLK: PMOD1.9, U2.4 (SCLK)
/ADC_SDATA: PMOD1.3, U2.3 (SDATA)
/CLK: PMOD1.7, U2.35 (CLKP)
/D1A+: PMOD2.1, U2.9 (DP1A)
/D1A-: PMOD2.2, U2.10 (DN1A)
/D1B+: PMOD2.7, U2.11 (DP1B)
/D1B-: PMOD2.8, U2.12 (DN1B)
/FCLK+: PMOD2.9, U2.19 (FCLKP)
/FCLK-: PMOD2.10, U2.20 (FCLPN)
/LCLK+: PMOD2.3, U2.17 (LCLKP)
/LCLK-: PMOD2.4, U2.18 (LCLKN)
/PWR_EN: PMOD1.2, R5.1, U1.3 (~SHDN)
/~ADC_RESET: PMOD1.4, U2.5 (RESETN)
ADC_1v8: C1.1, C3.1, C5.1, C6.1, C7.1, C9.1, C10.1, R8.2, U2.1 (AVDD), U2.7 (DVDD), U2.30 (DVDD), U2.32 (AVDD2), U2.36 (AVDD), U2.45 (AVDD)
GND: C1.2, C2.2, C3.2, C4.2, C5.2, C6.2, C7.2, C9.2, C10.2, C14.2, C15.2, C16.1, C17.2, J2.1, J2.3, PMOD1.5, PMOD1.11, PMOD2.5, PMOD2.11, R5.2, R7.1, U1.4 (GND), U2.8 (DVSS), U2.29 (DVSS), U2.31 (AVSS2), U2.34 (CLKN), U2.39 (AVSS), U2.42 (AVSS)
unnamed: C11.2, R1.1
unnamed: C12.2, R2.1
unnamed: C12.1, J1.1
unnamed: C11.1, J1.2
unnamed: R6.1, R7.2, U1.7 (ADJ)
unnamed: C16.2, U1.6 (Cdelay)
unnamed: C17.1, R6.2, R8.1, U1.8 (Vout)
unnamed: C13.1, R1.2, R3.1, U2.46 (IN1)
unnamed: C13.2, R2.2, R4.2, U2.47 (IP1)
VCM: C14.1, R3.2, R4.1, U2.48 (VCM)

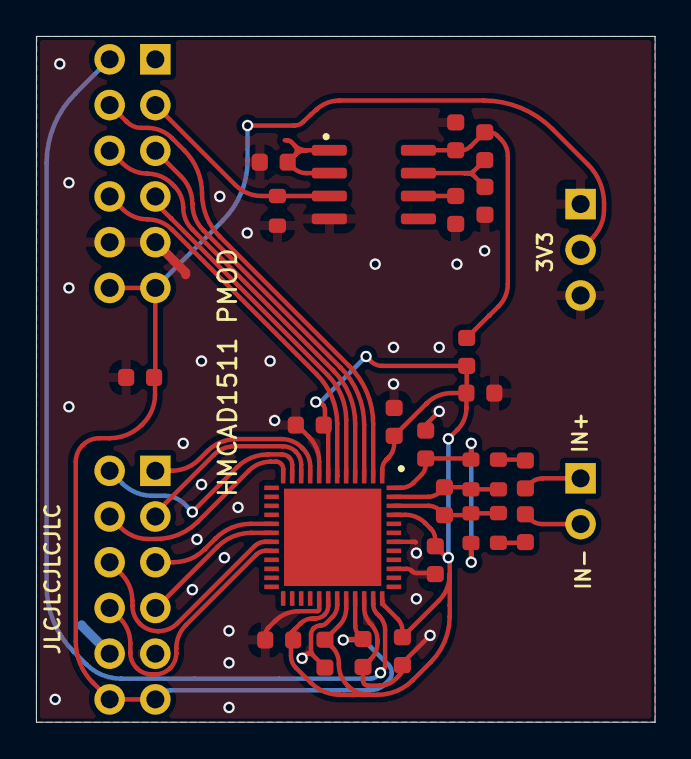
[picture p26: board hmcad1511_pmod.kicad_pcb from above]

Board: 2 copper layers, 34.4 x 38.1 mm, 30 parts (0 on the bottom side), 28 nets.

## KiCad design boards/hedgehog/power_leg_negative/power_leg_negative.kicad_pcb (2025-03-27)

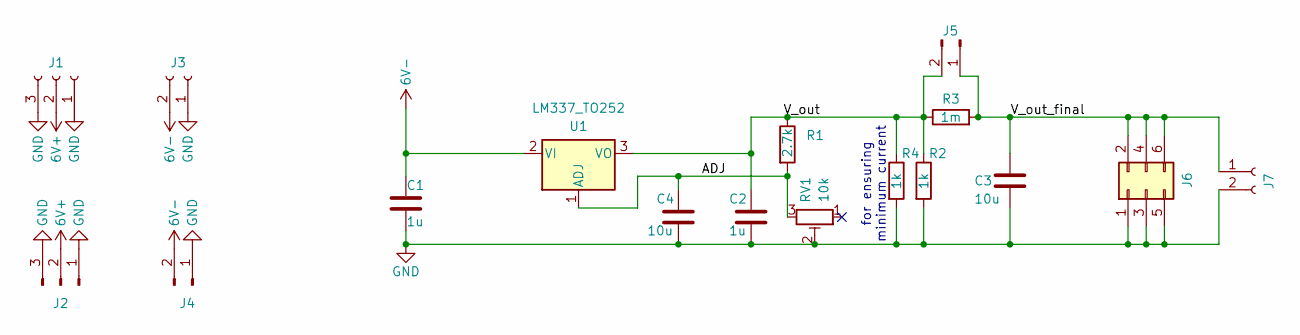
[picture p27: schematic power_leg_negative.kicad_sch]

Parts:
C1, C2: 1u; C_0603_1608Metric
C3, C4: 10u; C_0603_1608Metric
J1: Conn_01x03_Socket; PinSocket_1x03_P2.54mm_Horizontal
J2: Conn_01x03_Pin; PinHeader_1x03_P2.54mm_Horizontal
J3, J7: Conn_01x02_Socket; PinSocket_1x02_P2.54mm_Horizontal
J4: Conn_01x02_Pin; PinHeader_1x02_P2.54mm_Horizontal
J5: Conn_01x02_Pin; PinHeader_1x02_P2.54mm_Vertical
J6: Conn_02x03_Odd_Even; PinHeader_2x03_P2.54mm_Vertical
R1: 2.7k; R_0603_1608Metric
R2, R4: 1k; R_0603_1608Metric
R3: 1m; R_1206_3216Metric
RV1: 10k; Potentiometer_Bourns_3296W_Vertical; MPN C118963
U1: LM337_TO252; TO-252-2

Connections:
6V+: J1.2, J2.2
6V-: C1.1, J3.2, J4.2, U1.2 (VI)
/ADJ: C4.1, R1.2, RV1.3, U1.1 (ADJ)
/V_out: C2.1, J5.2, R1.1, R2.1, R3.1, R4.1, U1.3 (VO)
/V_out_final: C3.1, J5.1, J6.2, J6.4, J6.6, J7.1, R3.2
GND: C1.2, C2.2, C3.2, C4.2, J1.1, J1.3, J2.1, J2.3, J3.1, J4.1, J6.1, J6.3, J6.5, J7.2, R2.2, R4.2, RV1.2

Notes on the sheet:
for ensuring minimum current

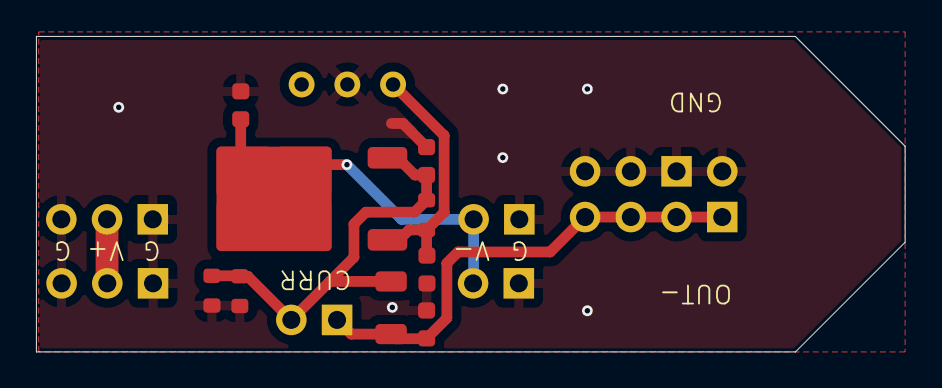
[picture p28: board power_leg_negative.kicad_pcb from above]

Board: 2 copper layers, 48.3 x 17.5 mm, 17 parts (0 on the bottom side), 6 nets.

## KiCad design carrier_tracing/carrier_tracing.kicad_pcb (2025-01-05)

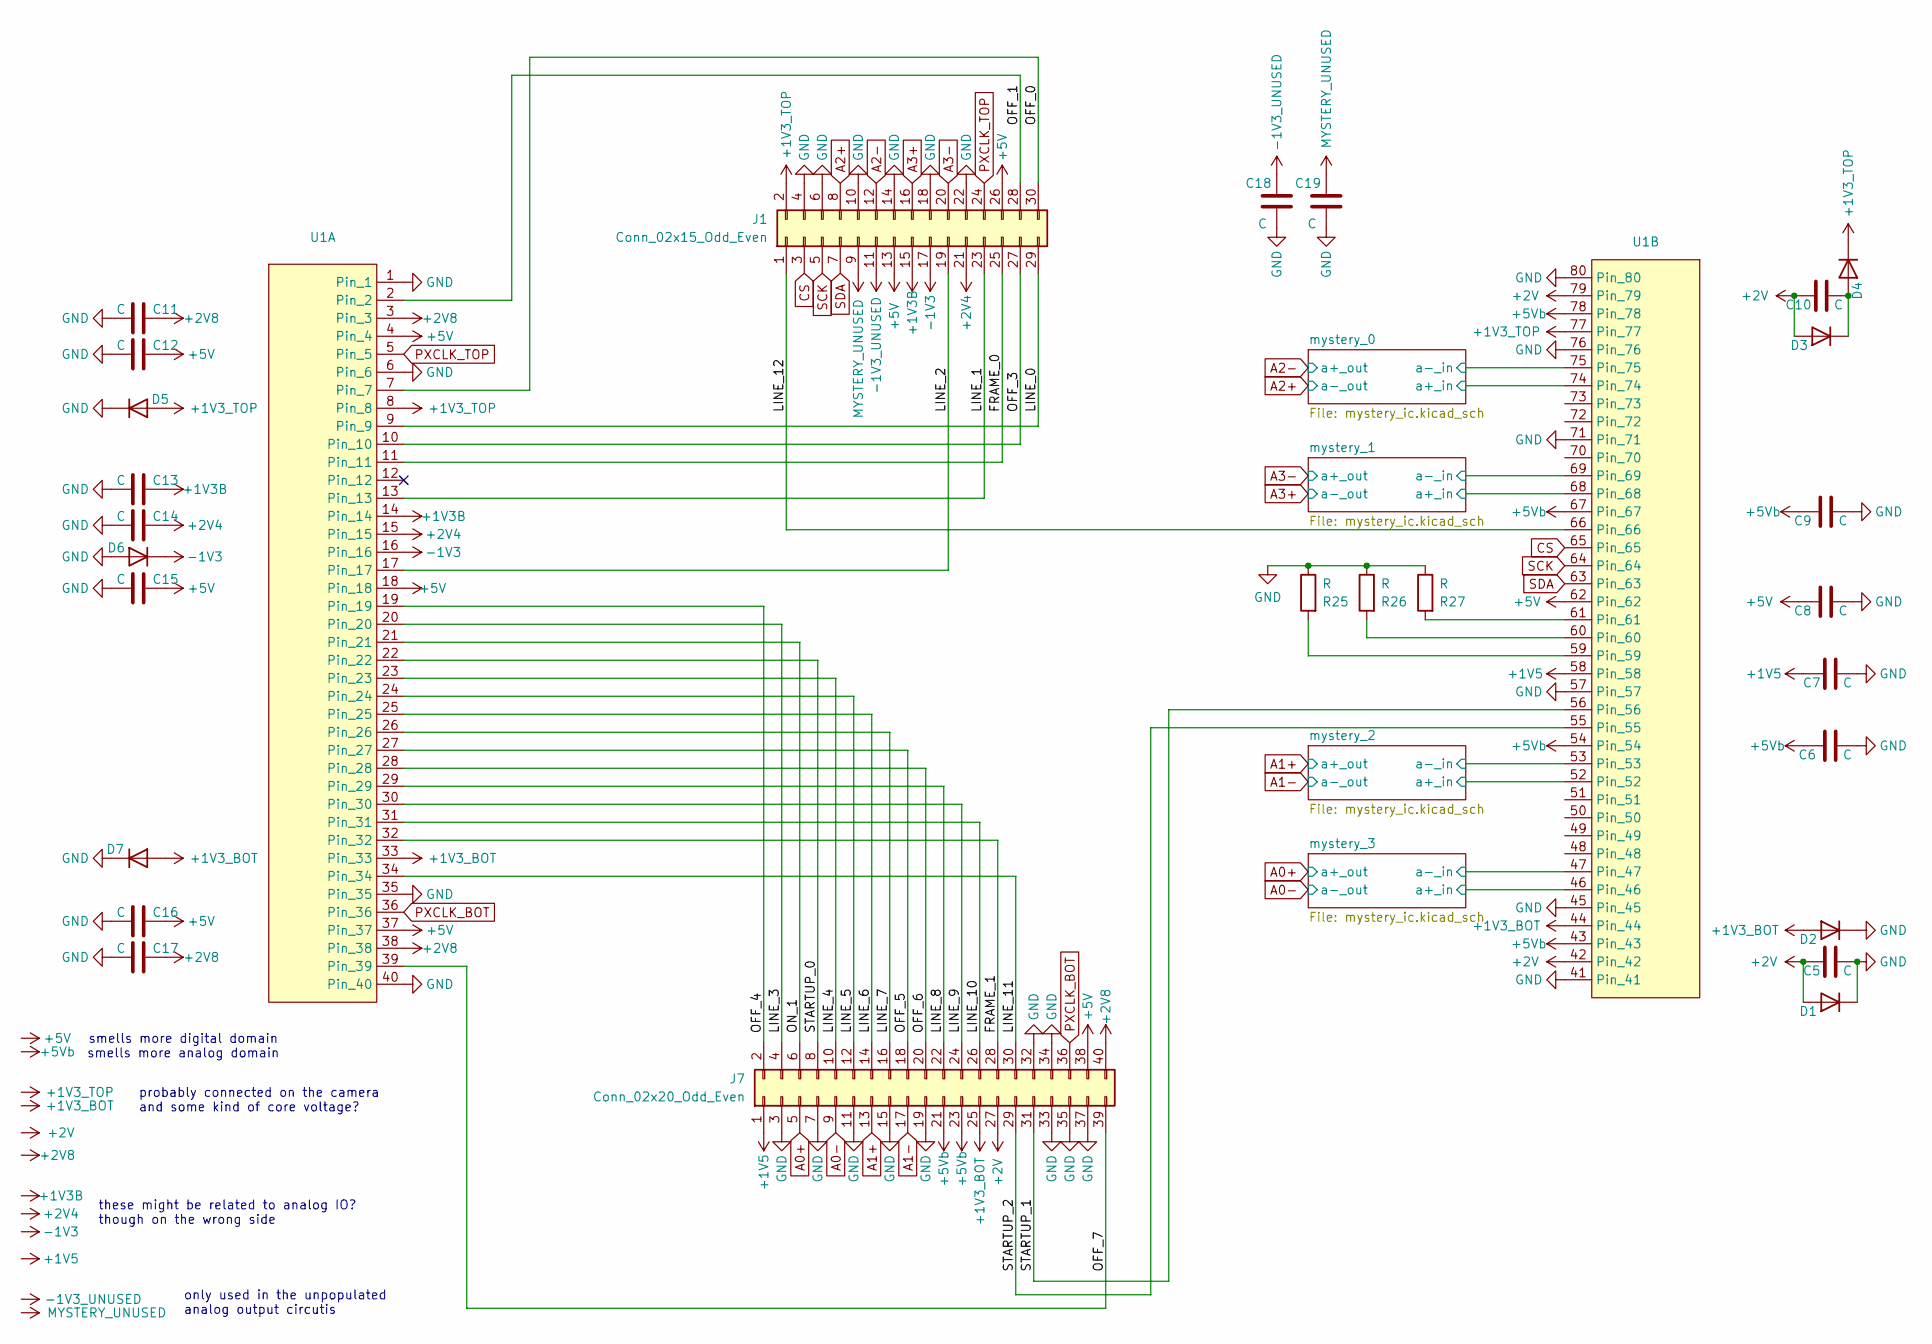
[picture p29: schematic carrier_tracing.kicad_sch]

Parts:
C5, C6, C7, C8, C9, C10, C11, C12, C13, C14, C15, C16, C17, C18, C19: C; C_0603_1608Metric
D1, D2, D3, D4, D5, D6, D7: D; D_0603_1608Metric
J1: Conn_02x15_Odd_Even; AXK5F30
J7: Conn_02x20_Odd_Even; AXK5F40
R25, R26, R27: R; R_0603_1608Metric
U1: 2d5

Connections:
+1V3B: C13.1, J1.15, U1.14
+1V3_BOT: D2.2 (A), D7.2 (A), J7.25, U1.33, U1.44
+1V3_TOP: D4.1 (K), D5.2 (A), J1.2, U1.8, U1.77
+1V5: C7.1, J7.1, U1.58
+2V: C5.1, C10.1, D1.2 (A), D3.2 (A), J7.27, U1.42, U1.79
+2V4: C14.1, J1.21, U1.15
+2V8: C11.1, C17.1, J7.40, U1.3, U1.38
+5V: C8.1, C12.1, C15.1, C16.1, J1.13, J1.26, J7.38, U1.4, U1.18, U1.37, U1.62
+5Vb: C6.1, C9.1, J7.21, J7.23, U1.43, U1.54, U1.67, U1.78
-1V3: D6.1 (K), J1.17, U1.16
-1V3_UNUSED: C18.1, J1.11; also elsewhere on the board
/FRAME_0: J1.25, U1.11
/FRAME_1: J7.28, U1.32
/LINE_0: J1.29, U1.9
/LINE_1: J1.23, U1.13
/LINE_2: J1.19, U1.17
/LINE_3: J7.4, U1.20
/LINE_4: J7.10, U1.23
/LINE_5: J7.12, U1.24
/LINE_6: J7.14, U1.25
/LINE_7: J7.16, U1.26
/LINE_8: J7.22, U1.29
/LINE_9: J7.24, U1.30
/LINE_10: J7.26, U1.31
/LINE_11: J7.30, U1.34
/LINE_12: J1.1, U1.66
/OFF_0: J1.30, U1.7
/OFF_1: J1.28, U1.2
/OFF_3: J1.27, U1.10
/OFF_4: J7.2, U1.19
/OFF_5: J7.18, U1.27
/OFF_6: J7.20, U1.28
/OFF_7: J7.39, U1.39
/ON_1: J7.6, U1.21
/STARTUP_0: J7.8, U1.22
/STARTUP_1: J7.31, U1.56
/STARTUP_2: J7.29, U1.55
/mystery_0/a+_in: U1.74; also elsewhere on the board
/mystery_0/a-_in: U1.75; also elsewhere on the board
/mystery_1/a+_in: U1.68; also elsewhere on the board
/mystery_1/a-_in: U1.69; also elsewhere on the board
/mystery_2/a+_in: U1.52; also elsewhere on the board
/mystery_2/a-_in: U1.53; also elsewhere on the board
/mystery_3/a+_in: U1.46; also elsewhere on the board
/mystery_3/a-_in: U1.47; also elsewhere on the board
A0+: J7.5; also elsewhere on the board
A0-: J7.9; also elsewhere on the board
A1+: J7.13; also elsewhere on the board
A1-: J7.17; also elsewhere on the board
A2+: J1.8; also elsewhere on the board
A2-: J1.12; also elsewhere on the board
A3+: J1.16; also elsewhere on the board
A3-: J1.20; also elsewhere on the board
CS: J1.3, U1.65
GND: C5.2, C6.2, C7.2, C8.2, C9.2, C11.2, C12.2, C13.2, C14.2, C15.2, C16.2, C17.2, C18.2, C19.2, D1.1 (K), D2.1 (K), D5.1 (K), D6.2 (A), D7.1 (K), J1.4, J1.6, J1.10, J1.14, J1.18, J1.22, J7.3, J7.7, J7.11, J7.15, J7.19, J7.32, J7.33, J7.34, J7.35, J7.37, R25.1, R26.1, R27.1, U1.1, U1.6, U1.35, U1.40, U1.41, U1.45, U1.57, U1.71, U1.76, U1.80
MYSTERY_UNUSED: C19.1, J1.9; also elsewhere on the board
unnamed: C10.2, D3.1 (K), D4.2 (A)
unnamed: R25.2, U1.59
unnamed: R26.2, U1.60
unnamed: R27.2, U1.61
PXCLK_BOT: J7.36, U1.36
PXCLK_TOP: J1.24, U1.5
SCK: J1.5, U1.64
SDA: J1.7, U1.63

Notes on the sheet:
only used in the unpopulated analog output circutis
these might be related to analog IO? though on the wrong side
smells more digital domain smells more analog domain
probably connected on the camera and some kind of core voltage?

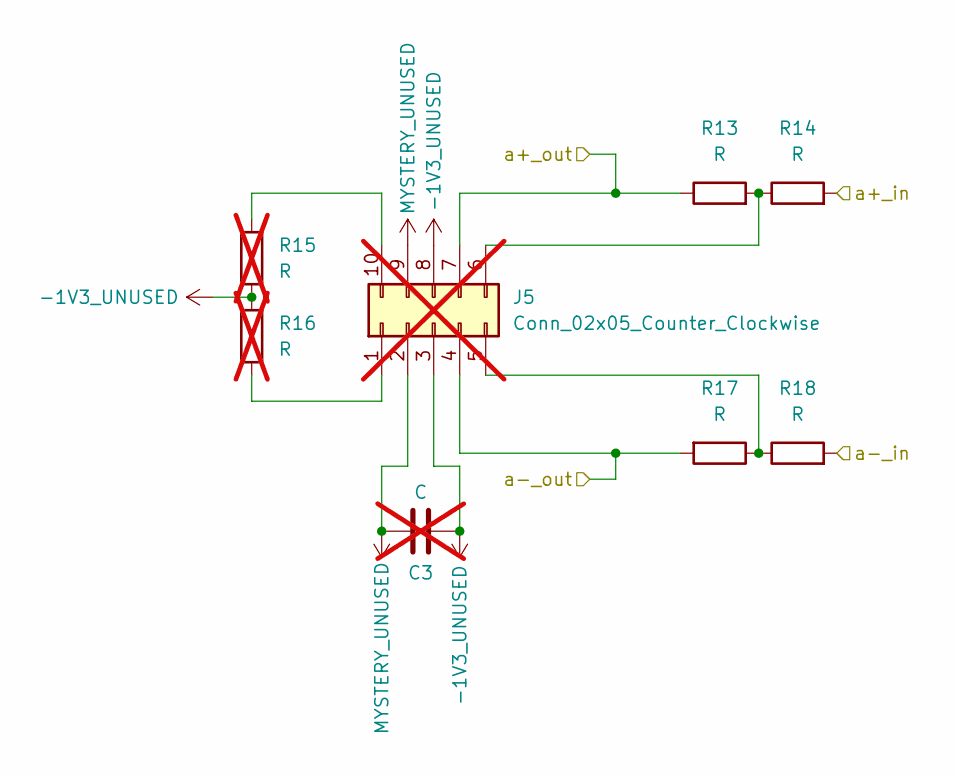
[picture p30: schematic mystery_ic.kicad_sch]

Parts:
C3: C; R_0603_1608Metric; not fitted
J5: Conn_02x05_Counter_Clockwise; SOIC-10; not fitted
R13, R14, R17, R18: R; R_0603_1608Metric
R15, R16: R; R_0603_1608Metric; not fitted

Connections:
-1V3_UNUSED: C3.2, J5.3, J5.8, R15.2, R16.1; also elsewhere on the board
/mystery_1/a+_in: R14.2; also elsewhere on the board
/mystery_1/a-_in: R18.2; also elsewhere on the board
A3+: J5.4, R17.2; also elsewhere on the board
A3-: J5.7, R13.1; also elsewhere on the board
MYSTERY_UNUSED: C3.1, J5.2, J5.9; also elsewhere on the board
unnamed: J5.1, R16.2
unnamed: J5.5, R17.1, R18.1
unnamed: J5.6, R13.2, R14.1
unnamed: J5.10, R15.1

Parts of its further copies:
C1, C2, C4: C; R_0603_1608Metric; not fitted
J3, J4, J6: Conn_02x05_Counter_Clockwise; SOIC-10; not fitted
R1, R2, R5, R6, R7, R8, R11, R12, R21, R22, R23, R24: R; R_0603_1608Metric
R3, R4, R9, R10, R19, R20: R; R_0603_1608Metric; not fitted

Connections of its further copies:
-1V3_UNUSED: C1.2, C2.2, C4.2, J3.3, J3.8, J4.3, J4.8, J6.3, J6.8, R3.2, R4.1, R9.2, R10.1, R19.2, R20.1; also elsewhere on the board
/mystery_0/a+_in: R23.2; also elsewhere on the board
/mystery_0/a-_in: R24.2; also elsewhere on the board
/mystery_2/a+_in: R2.2; also elsewhere on the board
/mystery_2/a-_in: R6.2; also elsewhere on the board
/mystery_3/a+_in: R8.2; also elsewhere on the board
/mystery_3/a-_in: R12.2; also elsewhere on the board
A0+: J4.7, R7.1; also elsewhere on the board
A0-: J4.4, R11.2; also elsewhere on the board
A1+: J3.7, R1.1; also elsewhere on the board
A1-: J3.4, R5.2; also elsewhere on the board
A2+: J6.4, R22.2; also elsewhere on the board
A2-: J6.7, R21.1; also elsewhere on the board
MYSTERY_UNUSED: C1.1, C2.1, C4.1, J3.2, J3.9, J4.2, J4.9, J6.2, J6.9; also elsewhere on the board
unnamed: J3.1, R4.2
unnamed: J3.5, R5.1, R6.1
unnamed: J3.6, R1.2, R2.1
unnamed: J3.10, R3.1
unnamed: J4.1, R10.2
unnamed: J4.5, R11.1, R12.1
unnamed: J4.6, R7.2, R8.1
unnamed: J4.10, R9.1
unnamed: J6.1, R20.2
unnamed: J6.5, R22.1, R24.1
unnamed: J6.6, R21.2, R23.1
unnamed: J6.10, R19.1

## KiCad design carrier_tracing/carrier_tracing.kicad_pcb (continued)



Board: 2 copper layers, 60 parts (59 on the bottom side), 80 nets.

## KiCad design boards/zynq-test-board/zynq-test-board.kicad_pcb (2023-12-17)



Board: 4 copper layers, 94.0 x 94.0 mm, 206 parts (201 on the bottom side), 199 nets.

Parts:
A1: Z-TURN-LITE; CONN_BTH-060-XX-X-D-LC
A2: 2d5_flat
C1, C3, C6, C8, C14, C16, C22, C24, C30, C32, C35, C42, C44, C47, C49: 1u; C_0603_1608Metric
C2, C7, C9, C10, C15, C17, C18, C23, C25, C26, C31, C33, C34, C36, C37, C43, C45, C46, C50, C51, C54, C55, C56, C57, C59, C60, C64, C65, C66: 0.1u; C_0603_1608Metric
C11, C12, C19, C20, C27, C28, C61, C62: 100n; C_0603_1608Metric
C13, C21, C29, C63: 22pF; C_0603_1608Metric
C38: 100p; C_0603_1608Metric
C39, C40, C41, C48, C52, C53, C58: 10u; C_0805_2012Metric
D1, D2, D3: D_Schottky; D_SMA
H1, H2, H3, H4: MountingHole_Pad; MountingHole_3.2mm_M3_Pad
L1: 10u; L_Abracon_ASPI-0630LR
R1: 0; C_0603_1608Metric
R2, R43: 10k; R_0603_1608Metric
R3, R4, R5: 22k; R_0603_1608Metric
R6: 6k8; R_0603_1608Metric
R7: 8k2; C_0603_1608Metric
R8: 27k; C_0603_1608Metric
R9, R10, R11, R19, R27, R35, R44, R48, R59, R60, R61, R62, R95, R96, R97, R98, R108, R109, R110: 0; R_0603_1608Metric_Pad0.98x0.95mm_HandSolder
R12, R20, R28, R36, R45, R50: 10m; R_0603_1608Metric
R13, R14, R21, R22, R29, R30, R37, R38, R46, R47, R51, R52: 10; R_0603_1608Metric
R15, R16, R23, R24, R31, R32, R55, R56: 22; R_0603_1608Metric
R17, R18, R25, R26, R33, R34, R57, R58: 1k; R_0603_1608Metric
R39: 40k; R_0603_1608Metric
R40: 2.55k; R_0603_1608Metric
R41: 1R; R_0805_2012Metric
R42: 39k; R_0603_1608Metric
R49: 47k; R_0603_1608Metric
R53, R54, R99, R100, R101, R102, R103, R104, R105, R106, R107: 4k7; R_0603_1608Metric
R63, R64, R65, R66, R67, R68, R69, R70, R71, R72, R73, R74, R75, R76, R77, R78, R79, R80, R81, R82, R83, R84, R85, R86, R87, R88, R89, R90, R91, R92, R93, R94: 220; R_0603_1608Metric_Pad0.98x0.95mm_HandSolder
RV2, RV3, RV4, RV5, RV6, RV7: 100k; Potentiometer_Bourns_3296W_Vertical
U1, U3, U5, U7, U9, U12: MCP1727-ADJxSN; SOIC-8_3.9x4.9mm_P1.27mm
U4, U6, U8, U10, U13, U16: INA226; VSSOP-10_3x3mm_P0.5mm
U11: TPS55340PWPR; PWP14
U15: LM337_TO252; TO-252-2
U17: ISO1541; SOIC-8_3.9x4.9mm_P1.27mm
U18: HMCAD1511; QFN_48_ADI

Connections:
+2V5: A1.19 (VDDIO_35_PL), A1.20 (VDDIO_35_PL), C22.1, C30.1, C53.1, C55.1, U7.1 (Vin), U7.2 (Vin), U9.1 (Vin), U9.2 (Vin), U18.33 (OVDD)
+3V3: A1.70 (VDDIO_34_PL), A1.81 (VDDIO_34_PL), C1.1, C10.1, C14.1, C18.1, C26.1, C34.1, C46.1, C65.1, R99.1, R100.1, U1.1 (Vin), U1.2 (Vin), U4.6 (VS), U5.1 (Vin), U5.2 (Vin), U6.2 (A0), U6.6 (VS), U8.6 (VS), U10.6 (VS), U13.1 (A1), U13.2 (A0), U13.6 (VS), U17.1 (VCC1)
+5V: A1.115 (VDD_5V), A1.116 (VDD_5V), A1.117 (VDD_5V), A1.118 (VDD_5V), A1.119 (VDD_5V), A1.120 (VDD_5V), C6.1, R110.1, U3.1 (Vin), U3.2 (Vin)
/ADC/A1+: A2.D12 (A2+), C20.1
/ADC/A1-: A2.D14 (A2-), C19.1
/ADC/A2+: A2.D8 (A1+), C12.1
/ADC/A2-: A2.D10 (A1-), C11.1
/ADC/A3+: A2.I14 (A3+), C62.1
/ADC/A3-: A2.I16 (A3-), C61.1
/ADC/A4+: A2.I18 (A4+), C28.1
/ADC/A4-: A2.I20 (A4-), C27.1
/ADC/ADC_CSN: A1.13 (IO_B35_LP16), U18.2 (CSN)
/ADC/ADC_PD: A1.9 (IO_B35_LP5), U18.6 (PD)
/ADC/ADC_SCLK: A1.5 (IO_B35_LN2), U18.4 (SCLK)
/ADC/ADC_SDATA: A1.11 (IO_B35_LN5), U18.3 (SDATA)
/ADC/CLK+: A1.56 (IO_B35_LP23), U18.35 (CLKP)
/ADC/CLK-: A1.58 (IO_B35_LN23), U18.34 (CLKN)
/ADC/D1A+: A1.4 (IO_B35_LP3), U18.9 (DP1A)
/ADC/D1A-: A1.6 (IO_B35_LN3), U18.10 (DN1A)
/ADC/D1B+: A1.10 (IO_B35_LP4), U18.11 (DP1B)
/ADC/D1B-: A1.12 (IO_B35_LN4), U18.12 (DN1B)
/ADC/D2A+: A1.14 (IO_B35_LP6), U18.13 (DP2A)
/ADC/D2A-: A1.16 (IO_B35_LN6), U18.14 (DN2A)
/ADC/D2B+: A1.22 (IO_B35_LP17), U18.15 (DP2B)
/ADC/D2B-: A1.24 (IO_B35_LN17), U18.16 (DN2B)
/ADC/D3A+: A1.32 (IO_B35_LP10), U18.21 (DP3A)
/ADC/D3A-: A1.34 (IO_B35_LN10), U18.22 (DN3A)
/ADC/D3B+: A1.36 (IO_B35_LP19), U18.23 (DP3B)
/ADC/D3B-: A1.38 (IO_B35_LN19), U18.24 (DN3B)
/ADC/D4A+: A1.42 (IO_B35_LP20), U18.25 (DP4A)
/ADC/D4A-: A1.44 (IO_B35_LN20), U18.26 (DN4A)
/ADC/D4B+: A1.52 (IO_B35_LP22), U18.27 (DP4B)
/ADC/D4B-: A1.54 (IO_B35_LN22), U18.28 (DN4B)
/ADC/FCLK+: A1.46 (IO_B35_LP13), U18.19 (FCLKP)
/ADC/FCLK-: A1.48 (IO_B35_LN13), U18.20 (FCLPN)
/ADC/LCLK+: A1.26 (IO_B35_LP12), U18.17 (LCLKP)
/ADC/LCLK-: A1.28 (IO_B35_LN12), U18.18 (LCLKN)
/ADC/filter 1/OUT_N: C21.1, R23.2, R25.1, U18.46 (IN1)
/ADC/filter 1/OUT_P: C21.2, R24.2, R26.2, U18.47 (IP1)
/ADC/filter 2/OUT_N: C13.1, R15.2, R17.1, U18.43 (IN2)
/ADC/filter 2/OUT_P: C13.2, R16.2, R18.2, U18.44 (IP2)
/ADC/filter 3/OUT_N: C63.1, R55.2, R57.1, U18.40 (IN3)
/ADC/filter 3/OUT_P: C63.2, R56.2, R58.2, U18.41 (IP3)
/ADC/filter 4/OUT_N: C29.1, R31.2, R33.1, U18.37 (IN4)
/ADC/filter 4/OUT_P: C29.2, R32.2, R34.2, U18.38 (IP4)
/ADC/~ADC_RESET: A1.3 (IO_B35_LP2), U18.5 (RESETN)
/Power/5v reg/Vin: C35.1, L1.1, R110.2, U11.3 (VIN)
/Power/5v reg/Vout+: C41.1, D1.1 (K), R42.1, R109.1
/Power/5v reg/Vout-: C40.1, D2.2 (A), R108.1
/Power/+6V: C42.1, R109.2, U12.1 (Vin), U12.2 (Vin)
/Power/-6V: C47.1, C51.2, C66.2, R108.2, U15.2 (VI), U16.2 (A0), U16.7 (GND), U17.5 (GND2)
/Power/negative 1v3/SCL_INT: R53.2, U16.5 (SCL), U17.6 (SCL2)
/Power/negative 1v3/SDA_INT: R54.2, U16.4 (SDA), U17.7 (SDA2)
/Power/sensor 1V5/ADJ: R4.1, RV4.2, U7.7 (ADJ)
/Power/sensor 1v3/ADJ: R5.1, RV5.2, U9.7 (ADJ)
/Power/sensor 2V/ADJ: R3.1, RV3.2, U5.7 (ADJ)
/Power/sensor 3V3/ADJ: R2.1, RV2.2, U3.7 (ADJ)
/Power/sensor 5V/ADJ: R6.1, RV6.2, U12.7 (ADJ)
/digital/FRAME_RST: A1.80 (IO_B34_LN15), R82.1
/digital/LINE0: A1.76 (IO_B34_LN19), R81.1
/digital/LINE1: A1.84 (IO_B34_LP16), R83.1
/digital/LINE2: A1.73 (IO_B34_LN13), R84.1
/digital/LINE3: A1.104 (IO_B34_LP17), R85.1
/digital/LINE5: A1.108 (IO_B34_LP8), R87.1
/digital/LINE6: A1.98 (IO_B34_LP18), R88.1
/digital/LINE7: A1.109 (IO_B34_LN7), R89.1
/digital/LINE8: A1.89 (IO_B34_LN12), R90.1
/digital/LINE9: A1.95 (IO_B34_LN22), R91.1
/digital/LINE10: A1.105 (IO_B34_LN10), R92.1
/digital/LINE11: A1.103 (IO_B34_LP10), R93.1
/digital/LINE_EXP: A1.106 (IO_B34_LN17), R86.1
/digital/LINE_RST: A1.93 (IO_B34_LP22), R94.1
/digital/PXCLK_BOT: A1.100 (IO_B34_LN18), R79.1
/digital/PXCLK_TOP: A1.62 (IO_B34_LP24), R80.1
/digital/SCLK: A1.63 (IO_B34_LN23), R64.1
/digital/SCS: A1.71 (IO_B34_LP13), R65.1
/digital/SDATA: A1.61 (IO_B34_LP23), R63.1
/digital/START0: A1.96 (IO_B34_LN21), R74.1
/digital/START1: A1.107 (IO_B34_LP7), R75.1
/digital/START2: A1.94 (IO_B34_LP21), R76.1
/digital/START3: A1.77 (IO_B34_LN14), R77.1
/digital/START4: A1.83 (IO_B34_LP9), R78.1
/digital/ZERO0: A1.75 (IO_B34_LP14), R66.1
/digital/ZERO1: A1.86 (IO_B34_LN16), R67.1
/digital/ZERO2: A1.78 (IO_B34_LP15), R68.1
/digital/ZERO3: A1.74 (IO_B34_LP19), R69.1
/digital/ZERO4: A1.64 (IO_B34_LN24), R70.1
/digital/ZERO5: A1.110 (IO_B34_LN8), R71.1
/digital/ZERO6: A1.85 (IO_B34_LN9), R72.1
/digital/ZERO7: A1.87 (IO_B34_LP12), R73.1
ADC_1v8: C52.1, C54.1, C56.1, C57.1, C58.1, C59.1, C60.1, C64.1, R1.2, U18.1 (AVDD), U18.7 (DVDD), U18.30 (DVDD), U18.32 (AVDD2), U18.36 (AVDD), U18.45 (AVDD)
EN_1V8_ADC: A1.33 (IO_B35_LN18), R107.1, U1.3 (~SHDN)
EN_SNS_1V3: A1.15 (IO_B35_LN16), R104.1, U9.3 (~SHDN)
EN_SNS_1V5: A1.21 (IO_B35_LP14), R103.1, U7.3 (~SHDN)
EN_SNS_2V0: A1.23 (IO_B35_LN14), R102.1, U5.3 (~SHDN)
EN_SNS_3V3: A1.25 (IO_B35_LP1), R101.1, U3.3 (~SHDN)
EN_SNS_5V: A1.27 (IO_B35_LN1), R105.1, U12.3 (~SHDN)
EN_SNS_HV: A1.31 (IO_B35_LP18), R106.1, U11.4 (EN)
GND: A1.7 (DGND), A1.8 (DGND), A1.17 (DGND), A1.18 (DGND), A1.29 (DGND), A1.30 (DGND), A1.39 (DGND), A1.40 (DGND), A1.49 (DGND), A1.50 (DGND), A1.59 (DGND), A1.60 (DGND), A1.69 (DGND), A1.72 (DGND), A1.79 (DGND), A1.82 (DGND), A1.91 (DGND), A1.92 (DGND), A1.101 (DGND), A1.102 (DGND), A1.111 (DGND), A1.112 (DGND), A1.113 (DGND), A2.D7 (GND), A2.D9 (GND), A2.D11 (GND), A2.D13 (GND), A2.D15 (GND), A2.D16 (GND), A2.I4 (GND), A2.I5 (GND), A2.I6 (GND), A2.I13 (GND), A2.I15 (GND), A2.I17 (GND), A2.I19 (GND), A2.I21 (GND), A2.J6 (GND), A2.J7 (GND), C1.2, C2.1, C3.2, C6.2, C7.1, C8.2, C10.2, C14.2, C15.1, C16.2, C18.2, C22.2, C23.1, C24.2, C26.2, C30.2, C31.1, C32.2, C34.2, C35.2, C36.2, C37.2, C38.2, C40.2, C41.2, C42.2, C43.1, C44.2, C46.2, C47.2, C48.2, C49.2, C51.1, C52.2, C53.2, C54.2, C55.2, C56.2, C57.2, C58.2, C59.2, C60.2, C64.2, C65.2, C66.1, D3.1 (K), H1.1, H2.1, H3.1, H4.1, R2.2, R3.2, R4.2, R5.2, R6.2, R8.1, R39.2, R43.2, R53.1, R54.1, R101.2, R102.2, R103.2, R104.2, R105.2, R106.2, R107.2, RV7.3, U1.4 (GND), U3.4 (GND), U4.1 (A1), U4.2 (A0), U4.7 (GND), U5.4 (GND), U6.1 (A1), U6.7 (GND), U7.4 (GND), U8.1 (A1), U8.7 (GND), U9.4 (GND), U10.1 (A1), U10.7 (GND), U11.6 (SYNC), U11.7 (AGND), U11.12 (PGND), U11.13 (PGND), U11.14 (PGND), U11.15 (EPAD), U12.4 (GND), U13.7 (GND), U16.1 (A1), U16.6 (VS), U17.4 (GND1), U17.8 (VCC2), U18.8 (DVSS), U18.29 (DVSS), U18.31 (AVSS2), U18.39 (AVSS), U18.42 (AVSS)
unnamed: A1.90 (IO_B34_LN20), R98.2
unnamed: A1.88 (IO_B34_LP20), R97.2
unnamed: A2.C10 (1V3), R35.2
unnamed: A2.D17 (1V3), R44.2
unnamed: A2.I10 (1V3), R48.2
unnamed: A2.I22 (1V5), R61.2
unnamed: A2.I9 (2V0), R62.2
unnamed: A2.C7 (3V3), R95.2
unnamed: A2.J20 (3V3), R96.2
unnamed: A2.C11 (5V), R10.2
unnamed: A2.D5 (5V), R9.2
unnamed: A2.I11 (5V), R19.2
unnamed: A2.I12 (5V), R27.2
unnamed: A2.J4 (5V), R11.2
unnamed: A2.C9 (-1V3), R59.2
unnamed: A2.C12 (-1V3), R60.2
unnamed: A2.J5 (PXCLK_BOT), R79.2
unnamed: A2.D6 (PXCLK_TOP), R80.2
unnamed: A2.C15 (SCLK), R64.2
unnamed: A2.C16 (SCS), R65.2
unnamed: A2.C14 (SDATA), R63.2
unnamed: A2.C5 (frame_rst), R82.2
unnamed: A2.C3 (line), R81.2
unnamed: A2.C6 (line), R83.2
unnamed: A2.C17 (line), R84.2
unnamed: A2.J8 (line), R85.2
unnamed: A2.J10 (line), R87.2
unnamed: A2.J11 (line), R88.2
unnamed: A2.J12 (line), R89.2
unnamed: A2.J15 (line), R90.2
unnamed: A2.J16 (line), R91.2
unnamed: A2.J17 (line), R92.2
unnamed: A2.J18 (line), R93.2
unnamed: A2.J9 (line_exp), R86.2
unnamed: A2.J21 (line_reset), R94.2
unnamed: A2.I3 (startup), R74.2
unnamed: A2.I7 (startup), R75.2
unnamed: A2.I8 (startup), R76.2
unnamed: A2.J13 (startup), R77.2
unnamed: A2.J19 (startup), R78.2
unnamed: A2.C4 (zero), R68.2
unnamed: A2.C8 (zero), R67.2
unnamed: A2.C13 (zero), R66.2
unnamed: A2.D3 (zero), R69.2
unnamed: A2.D4 (zero), R70.2
unnamed: A2.J3 (zero), R71.2
unnamed: A2.J14 (zero), R72.2
unnamed: A2.J22 (zero), R73.2
unnamed: C11.2, R15.1
unnamed: C12.2, R16.1
unnamed: C19.2, R23.1
unnamed: C20.2, R24.1
unnamed: C27.2, R31.1
unnamed: C28.2, R32.1
unnamed: C37.1, R40.2
unnamed: C39.1, R41.2
unnamed: C61.2, R55.1
unnamed: C62.2, R56.1
unnamed: D1.2 (A), L1.2, R41.1, U11.1 (SW), U11.2 (SW)
unnamed: C39.2, D2.1 (K), D3.2 (A)
unnamed: R7.1, R8.2, U1.7 (ADJ)
unnamed: C2.2, U1.6 (Cdelay)
unnamed: C3.1, R1.1, R7.2, U1.8 (Vout)
unnamed: C7.2, U3.6 (Cdelay)
unnamed: C8.1, R12.1, R13.2, RV2.3, U3.8 (Vout), U4.8 (Vbus)
unnamed: C9.1, R13.1, U4.10 (Vin+)
unnamed: C9.2, R14.2, U4.9 (Vin-)
unnamed: C15.2, U5.6 (Cdelay)
unnamed: C16.1, R20.1, R21.2, RV3.3, U5.8 (Vout), U6.8 (Vbus)
unnamed: C17.1, R21.1, U6.10 (Vin+)
unnamed: C17.2, R22.2, U6.9 (Vin-)
unnamed: C23.2, U7.6 (Cdelay)
unnamed: C24.1, R28.1, R29.2, RV4.3, U7.8 (Vout), U8.8 (Vbus)
unnamed: C25.1, R29.1, U8.10 (Vin+)
unnamed: C25.2, R30.2, U8.9 (Vin-)
unnamed: C31.2, U9.6 (Cdelay)
unnamed: C32.1, R36.1, R37.2, RV5.3, U9.8 (Vout), U10.8 (Vbus)
unnamed: C33.1, R37.1, U10.10 (Vin+)
unnamed: C33.2, R38.2, U10.9 (Vin-)
unnamed: C38.1, R40.1, U11.8 (COMP)
unnamed: R42.2, R43.1, U11.9 (FB)
unnamed: R39.1, U11.10 (FREQ)
unnamed: C36.1, U11.5 (SS)
unnamed: C43.2, U12.6 (Cdelay)
unnamed: C44.1, R45.1, R46.2, RV6.3, U12.8 (Vout), U13.8 (Vbus)
unnamed: C45.1, R46.1, U13.10 (Vin+)
unnamed: C45.2, R47.2, U13.9 (Vin-)
unnamed: R49.1, RV7.2, U15.1 (ADJ)
unnamed: C48.1, C49.1, R49.2, R50.1, R51.2, U15.3 (VO), U16.8 (Vbus)
unnamed: C50.1, R51.1, U16.10 (Vin+)
unnamed: C50.2, R52.2, U16.9 (Vin-)
SCL: R97.1, R100.2, U4.5 (SCL), U6.5 (SCL), U8.5 (SCL), U10.2 (A0), U10.5 (SCL), U13.5 (SCL), U17.2 (SDA1)
SDA: R98.1, R99.2, U4.4 (SDA), U6.4 (SDA), U8.2 (A0), U8.4 (SDA), U10.4 (SDA), U13.4 (SDA), U17.3 (SCL1)
Sensor+1V3: R35.1, R36.2, R38.1, R44.1, R48.1
Sensor+1V5: R28.2, R30.1, R61.1
Sensor+2V: R20.2, R22.1, R62.1
Sensor+3V3: R12.2, R14.1, R95.1, R96.1
Sensor+5V: R9.1, R10.1, R11.1, R19.1, R27.1, R45.2, R47.1
Sensor-1V3: R50.2, R52.1, R59.1, R60.1
VCM: R17.2, R18.1, R25.2, R26.1, R33.2, R34.1, R57.2, R58.1, U18.48 (VCM)

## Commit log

2023-10-19 add connector_breakout
    [connector_breakout-B_Cu.gbl, connector_breakout-B_Mask.gbs, connector_breakout-B_Paste.gbp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]
2023-11-03 do "static analysis" of the connector pinouts
    [connector_pinouts.ods]
2023-11-05 add logic analyser probing
    [connector_pinouts.ods]
2023-12-17 add more traces with different capture setup
2023-12-17 production version of zynq-test-board
    [5v_reg.kicad_sch, acd_filter.kicad_sch, adc.kicad_sch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]
2024-01-04 zynq-test-board: fix i2c addresses on power schematics
    [power.kicad_sch]
2024-08-21 update connector pinout script
    [connector_pinouts.ods]
2024-08-23 add code to analyze dumps
    [connector_pinouts.ods]
2025-01-05 move boards to seperate directory
    [5v_reg.kicad_sch, acd_filter.kicad_sch, adc.kicad_sch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]
2025-01-05 add carrier tracing project
    [carrier_tracing.kicad_pcb, carrier_tracing.kicad_sch, mystery_ic.kicad_sch]
2025-01-05 add connector pinout second try
    [connector_pinout_second_try.ods, connector_pinouts.ods]
2025-03-11 add more adc options
2025-03-27 add hedgehog boards
    this is the new generation testbed that is modular and where components should be reusable.
    the boards are ordered in the state committed here and assembled manually.
    [5d2_pmod-rounded.kicad_pcb, 5d2_pmod.kicad_pcb, 5d2_pmod.kicad_sch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]
2025-03-27 add update_schematics.sh and schematics pdf files
2025-03-27 secend revision of hedgehog/5d2_pmod board
    the first revision sadly had wrong row spacing for the sensor connectors and was thus unusable
    [5d2_pmod-rounded.kicad_pcb, 5d2_pmod.kicad_pcb, 5d2_pmod.kicad_sch]
2025-05-27 add gateware and software for live streaming hedgehog + sloth
